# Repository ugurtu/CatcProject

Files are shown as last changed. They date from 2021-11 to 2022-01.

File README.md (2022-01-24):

### CatcProject

This repository provides for the sensor Cube and its programms the following directories:
- building up the DHT-22 Sensor
- a code for a simple modell to use the DHT22 and the LEDs in combination. 
- The directory sensor Cube contains the whole code of the 4 x 4 x 4 LED Cube. 
- There is also the possibility to read out the Serial Port with the help of the python programs which are included in this repository. 

### General Information

- For the Arduino is the Arduino provided IDE used. 
- We used an Arduino UNO and Arduino ATMega 2560.
- For python used is PyCharm by JetBrains.

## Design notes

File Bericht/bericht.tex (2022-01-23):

\documentclass{article}
\usepackage{times}
\usepackage[nohead,bottom=3cm,top=2cm,a4paper]{geometry}
\usepackage[table]{xcolor}
\usepackage{graphicx}
\usepackage[nswissgerman]{babel}
\usepackage{listings}
\usepackage{blindtext}
\usepackage{enumitem}
\usepackage{xurl}
\usepackage{lipsum}
\usepackage{tikz}
\usepackage{hyperref}
\usepackage{float}
\usepackage{fontawesome}
\usepackage{mathtools}
\usetikzlibrary{positioning}
\usepackage{titletoc,tocloft}
\setlength{\cftsubsecindent}{2cm}
\setlength{\cftsubsubsecindent}{4cm}
\dottedcontents{section}[1.5em]{}{1.3em}{.6em}
\usepackage{amssymb,amsmath,amsthm}
\graphicspath{ {./results/} }
\usetikzlibrary{shadows,matrix} % Shadows for nodes
\usetikzlibrary{arrows.meta}
\title{Report aus dem Projekt sensor Cube}
\newlength\mylength
\setlength\mylength{\dimexpr.42\columnwidth-2\tabcolsep-0.42\arrayrulewidth\relax}
\usepackage[section]{placeins}
\def\l@subsection{\@tocline{2}{0pt}{2.5pc}{5pc}{}}	
\definecolor{Gray}{gray}{0.9}
\makeatletter
\renewcommand*\l@section{\@dottedtocline{1}{1.5em}{2.3em}}
\makeatother
\usepackage{varioref}

\author{von Ugur Turhal, Berkan Kurt \& Silvan Lenzlinger}
\begin{document}
\maketitle
\tableofcontents
%\addtocontents{toc}{\protect\thispagestyle{empty}}
\newpage
\begin{center}
\textbf{Abstract}
\end{center}
Dieses Report Dokument ist im Rahmen der Vorlesung, Rechenarchitektur \& vertrauenwürdiges Rechnen entstanden. Das Ziel war ein 4 x 4 x 4  Cube zu löten und diesen mit einem digitalen Luftfeuchtigkeits-\& Temperatursensor auszustatten.
Dieser soll anhand der Luftfeuchtigkeit und Temperatur, spezifische Muster ausgeben, welche uns verraten ob die Werte ideal sind für ein angenehmes Einschlafen. Alle Dokumente und Programme sind auffindbar unter: \begin{center}
\faGithub \text { }  \url{https://github.com/ugurtu/CatcProject}
\end{center}

%%%%
\section{Einleitung}
Als wir im November uns als Team zusammengesetzt haben war die Projektidee sofort klar. Wir wollten mit dem Projekt etwas schaffen, welches uns im alltäglichen Leben auch über den Projektzeitraum hinaus begleiten soll.
Nach reichlicher Überlegung entschieden wir uns für das Oberthema Schlaf. Wir haben den Schlaf gewählt, weil uns aufgefallen ist, dass wir alle drei unsere Einschlafphase als suboptimal beurteilen würden. Als wir uns über die Ursachen und Gründe für unseren suboptimalen Einschlafprozess ausgetausscht haben, kamen wir zum Entschluss, dass wir uns mit der optimalen Raumtemperatur nie auseinandergesetzt haben. Diese ist vor allem im Winter wichtig, da die Raumtemperatur sich zu dieser Jahreszeit oftmals über der optimalen Raumtemperatur, bedingt durch das Überheizen, befindet. Im nachfolgenden Report werden wir darüber reden, wie wir ein Gadget erstellt haben, welches uns hilft, dieses Problem zu lösen.

\section{Aufteilung}
\textbf{Ugur:} Bestellung, funktionsfähiges \glqq Circuit-Modell\grqq auf Tinkercad ohne DHT-22 Sensor, Programmierung des Python Codes zum Auslesen des Serial-Ports, C++ -Code Grundgerüst für den Cube und Jigs vorbereiten. Die Einzelnen Layers Löten. Siehe Kapitel \ref{section:Jigs}. Den Anderen zeigen wie richtig gelötet wird.\\ \\
\textbf{Berkan:} Kupferdraht richten mit Bohrmaschine und zuschneiden damit die Layers gleichmässig aussehen. Schrumpfschläuche über die Kabel ziehen und verlöten, welche mit den Layers Verbunden sind (Kathode), mit Hilfe von Ugur. Case aus Plexiglas herstellen mit Möglichkeit den Arduino in eine sichere Umgebung zu platzieren und einer Türmechanismus ähnlichen Oberfläche. \\ \\ \textbf{Silvan:} 88 LEDs in Form bringen mit Hilfe der Jigs. Mithilfe von Berkan und Ugur alle Layers verlöten Siehe Kapitel \ref{section:result} so dass ein Cube entsteht Siehe Kapitel \ref{section:Jigs}. Code von Ugur verfeinern, Fehler erkennen und ein clean Code entwickeln und Methodennamen anpassen. Cube Nachlöten falls etwas unsauber verlötet wurde. \\ \\
\textbf{Alle:} Bericht schreiben und den sensor Cube testen. 

\section{Jigs/Werkzeuge}
\label{section:Jigs}
Als Jigs werden Hilfsmittel bezeichnet, die beim Prozess des Fertigstellen das Leben vereinfachen. 
\begin{itemize}
\item Ein Raster aus Holz, in welchem die LEDs reingestellt und verlötet wurden. Siehe Abbildung \ref{fig:jig2}.
\item Ein Holzbrett, mit welchem die Anode und Kathode in Form gebracht wurden. Siehe Abbildung \ref{fig:jig1}
\item Eine Bohrmaschine, welche den Kupferdraht gerade gewickelt hat.
\item Ein Schraubstock, welches den Kupferdraht hielt.   
\end{itemize}

\begin{figure}[!h]
\begin{center}
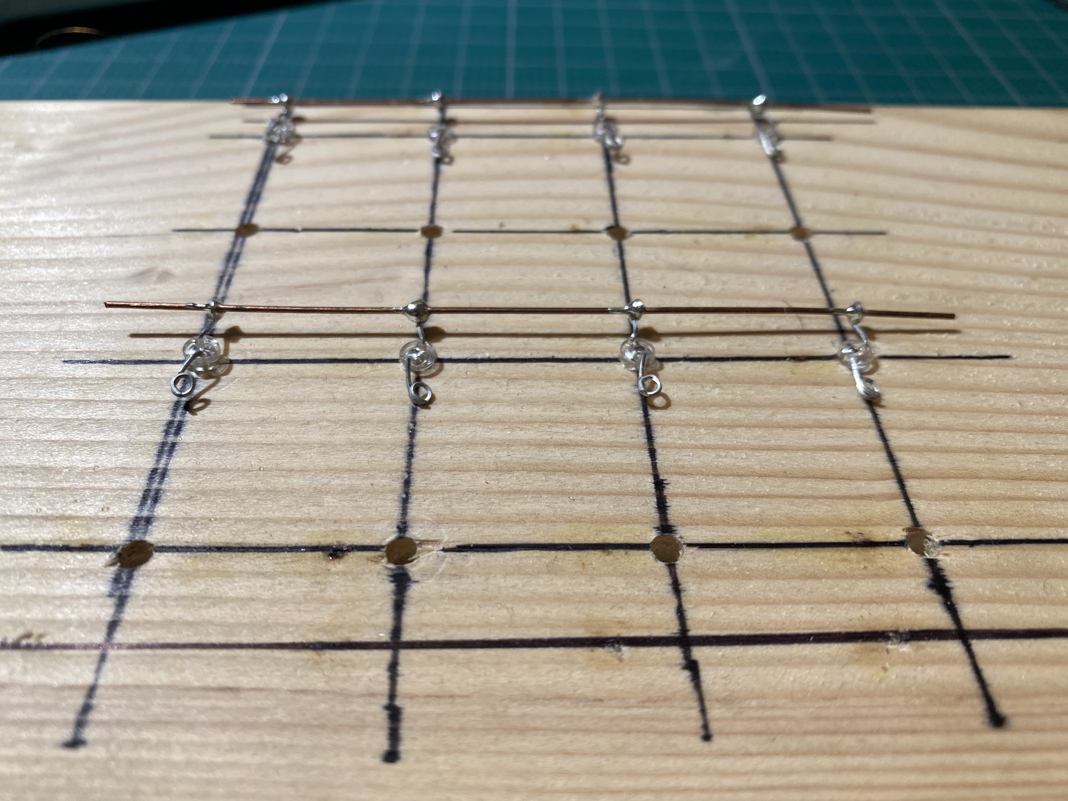
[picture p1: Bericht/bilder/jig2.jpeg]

\caption{Jig für die Layers}
\label{fig:jig2}
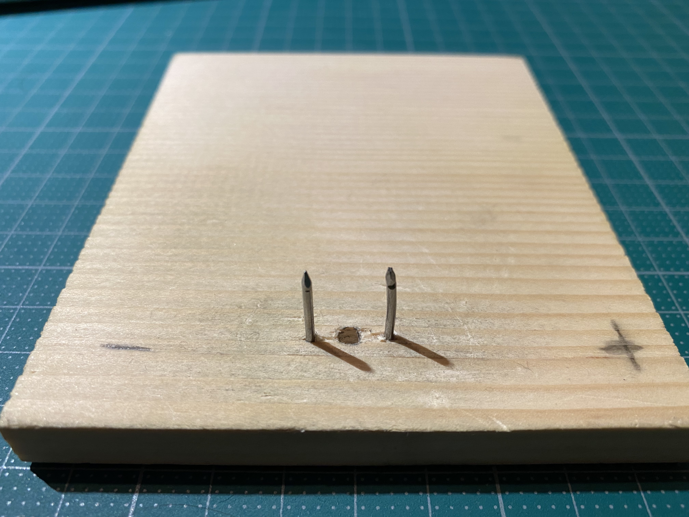
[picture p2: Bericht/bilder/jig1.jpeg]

\caption{Jig für die LEDs}
\label{fig:jig1}
\end{center}
\end{figure}

\noindent Die folgenden Werkzeuge wurden für die Kommunikation und als Austausch verwendet.
\begin{itemize}
\item GitHub, sorgte für einen reibungslosen Austausch.
\item WhatsApp, auf welchem die Meetings festgelegt wurden.
\item Zoom, für Onlinemeetings, falls jemand nicht anwesend war.
\item \LaTeX \text{ }für die Dokumentenerfassung.
\end{itemize} 
\section{Sammeln der Daten}
Bevor das Projekt begann, wurde für die Sicherstellung des Projektes der Sensor anhand des Serialports ausgelesen. Mittels Python Programmen wurde die Raumtemperatur gesammelt und geplotet. Genauere Aufbauinformationen findet man im Dokument:\textbf{ Aufbau.pdf}. Das Dokument befindet sich auf dem angegebenen GitHub Repository: \begin{itemize}
\item \url{https://github.com/ugurtu/CatcProject/blob/main/Aufbau\%20DHT\%2C\%20Programme\%20und\%20Daten/Aufbau.pdf}
\end{itemize} Den spezfischen Python Code findet man unter:
\begin{itemize}
\item  \url{https://github.com/ugurtu/CatcProject/tree/main/SerialPort_python}
\end{itemize}
Diesem Dokument aber liegen sowohl der Aufbau des Sensors und auch das Pythonprogramm bei. Wenn man Lüftet, sollte der Sensor in einer bestimmten Zeit eine Reaktion zeigen. Diese Reaktion verhaltet sich in Form von einem entsprechend angehenden LED Lämpchen. Dieses Testen und auslesen des Sensors diente für uns als Sicherstellung. Somit wurde uns klar, dass wir einen funktionstüchtigen Sensor besitzen, welchen wir für dieses Projekt ohne Probleme verwenden konnten.
\begin{figure}[!h]
\begin{center}
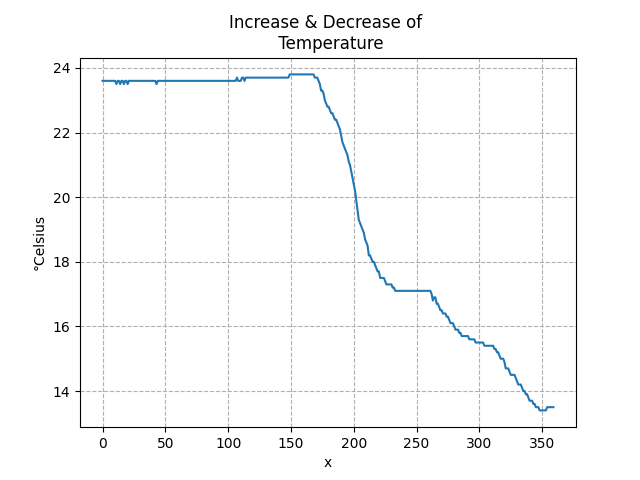
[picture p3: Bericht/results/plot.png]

\caption{Plot des Temperatur Anstiegs und der Abfall}
\label{fig:decrease}
\end{center}
\end{figure}
\begin{figure}[!h]
\begin{center}
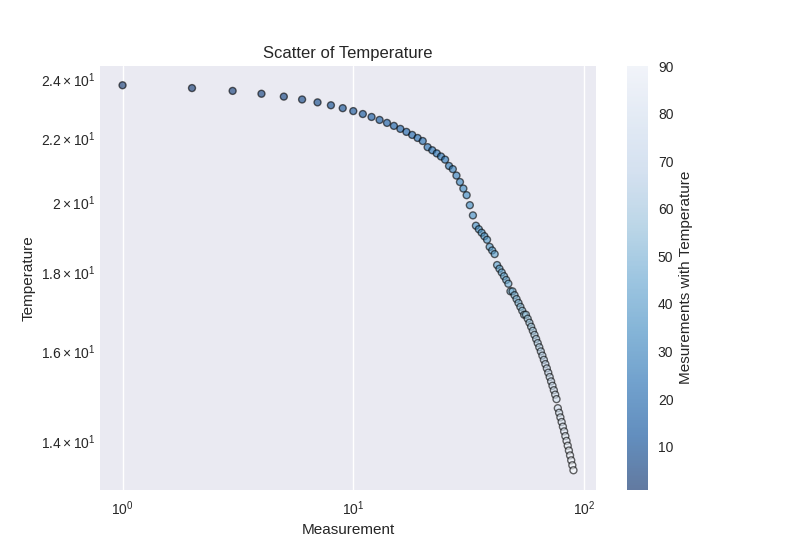
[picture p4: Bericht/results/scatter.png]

\caption{Scatter Plot des Temperatur Abfalls}
\label{fig:scatter}
\end{center}
\end{figure}
\vfill
\begin{figure}[!h]
\begin{center}
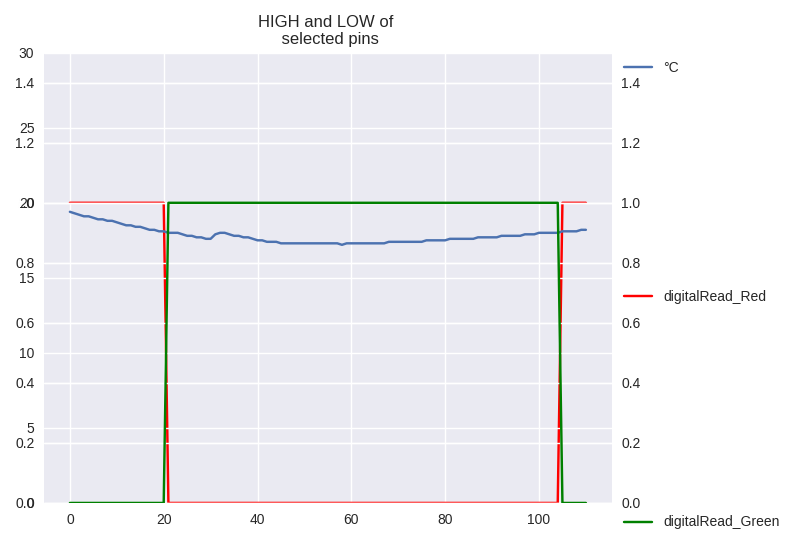
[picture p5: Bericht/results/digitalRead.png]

\caption{HIGH und LOW in einem ersten Test}
\label{fig:highlow}
\end{center}
\end{figure}
\newpage
\subsection{Erkenntnisse durch die Daten}
In der Abbildung \ref{fig:decrease} und \ref{fig:scatter} sieht man wie sich die Temperatur bei offenem Fenster zunehmend verringert. Somit hatten wir Gewissheit, dass der Sensor relativ schnell reagiert und für unser Projekt verwendbar ist. Die x - Achse in der Abbildung \ref{fig:decrease} ist die Zeit. Die Abbildung \ref{fig:scatter} ist Mesurement als 100 Messpunkte definiert. Alle doppelten Daten aus Abbildung \ref{fig:decrease} wurden ignoriert. In der Abbildung \ref{fig:highlow} sollen die zwei Farben, grün und rot, die Farben unserer LED’s und den Zustand HIGH and LOW repräsentieren. Sobald die Temperatur unter 18$^\circ$ C betrug, schalteten sich die grünen LED’s an (HIGH) und die roten LED’s aus (LOW). Damit wurde angezeigt, dass die Bedingung für das Einschlafen optimal ist. Sobald das Fenster wieder geschlossen und die Raumtemperatur damit wieder zugenommen hat, schalteten sich die grünen LED’s aus (LOW) und die roten LED’s gingen wieder an (HIGH).

\section{Umsetzung}
Unser Projekt hat in mehrheitlich sechs Phasen stattgefunden. Diese waren:
\begin{enumerate}[label=(\roman*)]
\item Einkauf
\item Prototyp auf Tinkercad
\item Einzelne Layers verlöten mit LEDs
\item Layers zu einem Cube verlöten
\item Cube mit Arduino verbinden
\item Case
\end{enumerate}
\textbf{Erster Punkt} Wir haben einige Sachen bewusst doppelt gekauft. Falls etwas defekt gewesen wäre, hätten wir keine Zeitengpässe gehabt. \\ \\ 
\textbf{Zweiter Punkt} Dieses folgende umgesetzte \glqq Circuit-Modell\grqq \text{ }wurde von der Grundstruktur so übernommen, allerdings soll angemerkt werden, dass dieses Modell mit einem Arudino UNO erstellt wurde, da kein Arduino ATMega auf Tinkercad zur Verfügung stand. Siehe: Abbildung \ref{fig:tinkercad}
\begin{figure}[h!]
\begin{center}
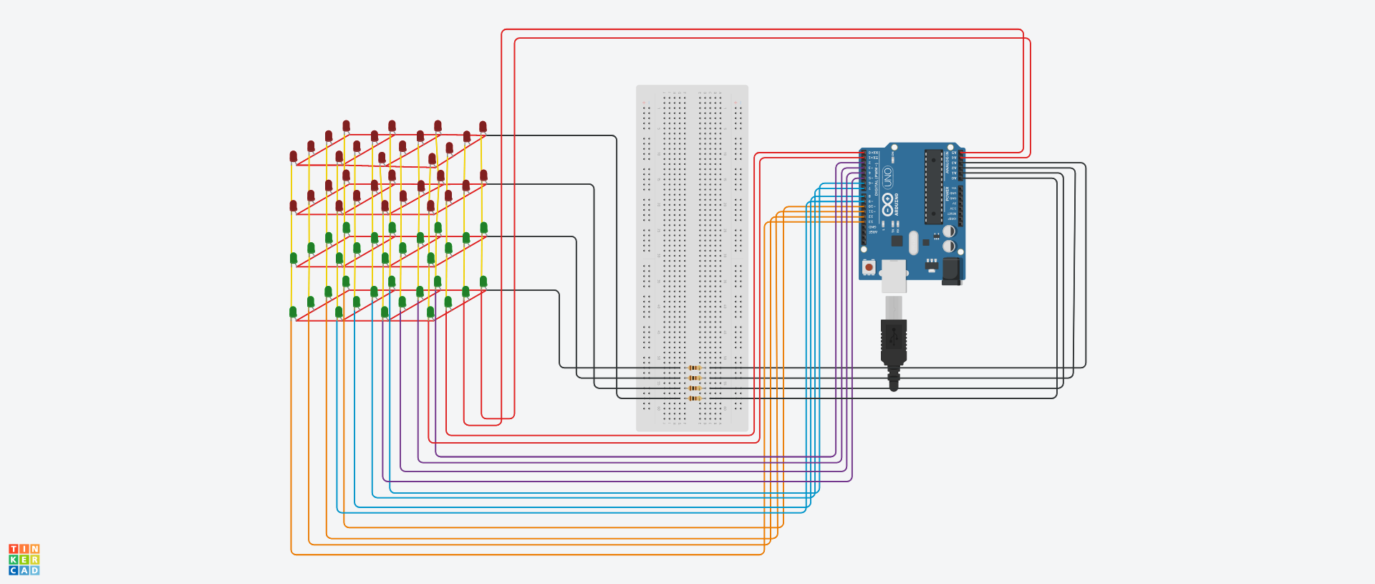
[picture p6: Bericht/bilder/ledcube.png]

\caption{LED Cube Circuit mit einem Arduino UNO}
\label{fig:tinkercad}
\end{center}
\end{figure}
\\ \\
\textbf{Dritter Punkt} Die Layers, welche in der Abbildung 7 zu sehen sind leiten den Strom. Es gibt vier davon. 
\begin{figure}[!h]
\begin{center}
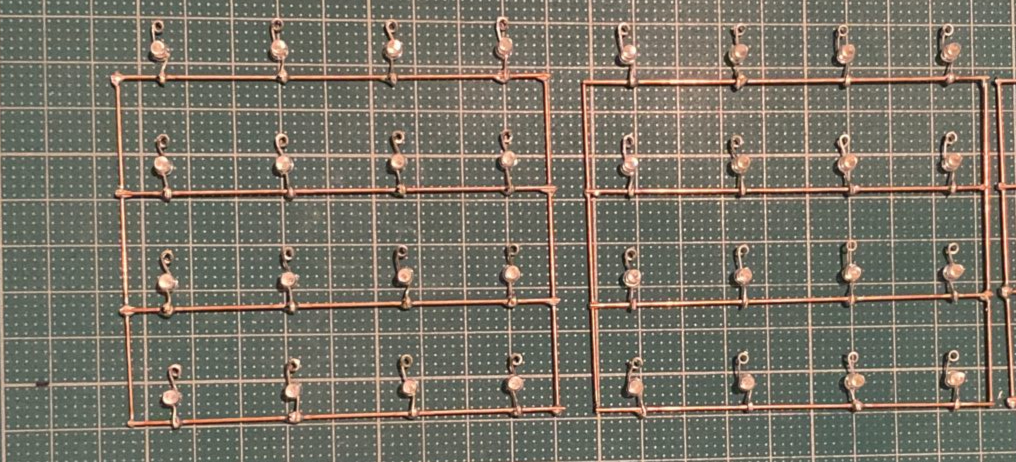
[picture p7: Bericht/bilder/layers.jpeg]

\label{fig:anode}
\caption{Anode mit dem Kupferdraht verlötet, zu sehen zwei Layers}
\end{center}
\end{figure}
\\ \\
\textbf{Vierter Punkt} Die Layers, werden durch vertikale Kupferdrähte miteinander verbunden, dies sorgt dafür dass die Kathode verbunden ist. Danach wurde der Cube mit der Europlatine verlötet. Damit jede Ebene, durch den Mikrocontroller Strom bekommt, wurden zusätzlich vier Kupferdrähte jeweils treppenförmig mit den vier Layers verbunden. Jeder Layer ist jeweils mit einem 100 $\Omega$ Widerstand verlötet. Das Datasheet für die LEDs sieht ein Peak Forward Current von 60 mA vor. Daher wurden 100 $\Omega$ verwendet.\footnote{\url{https://www.reichelt.com/de/en/led-3-mm-leaded-green-125-mcd-25--evl-1224-10sygc-p230786.html}} \begin{align}
U = R \cdot I \\
U \coloneqq 5 V, I \coloneqq 0.060 A \\
\frac{5V}{0.060A} = 83.333 \Omega \\
\approx 100 \Omega
\end{align}
Danach wurde auf der linken Seite des sensor Cubes der DHT-22 verlötet. Als letzter Schritt wurden die Kuperdrähte der Kathode und die Pins des Sensors mit Kabeln verlötet, isoliert und mit den Stiftleisten verlötet. Siehe Abbildung \ref{fig:kathode}. 
\begin{figure}[!h]
\begin{center}
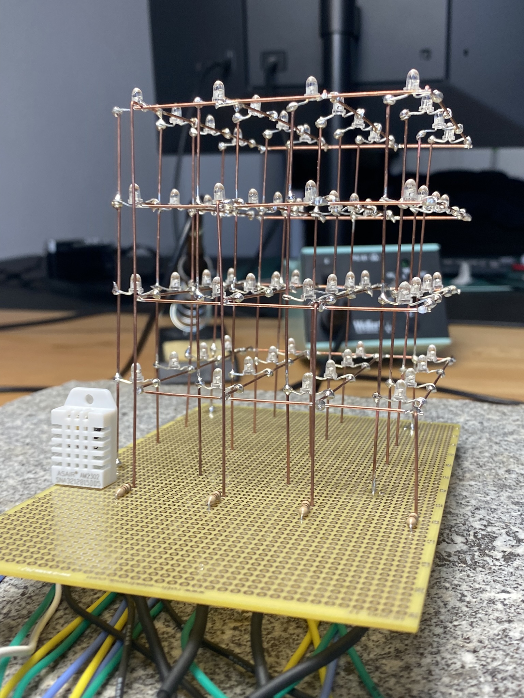
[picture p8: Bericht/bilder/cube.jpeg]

\caption{sensor Cube gelötet}
\label{fig:kathode}
\end{center}
\end{figure}\newpage
\noindent \textbf{Fünfter Punkt}
Der 5 Schritt war die entscheidende Phase, da alles fertig war wurden die Pins verbunden. hier eine Übersicht:
\begin{enumerate}
\item A0 $\rightarrow$ versorgt Layer 0 mit Strom.
\item A1 $\rightarrow$ versorgt Layer 1 mit Strom.
\item A2 $\rightarrow$ versorgt Layer 2 mit Strom.
\item A3 $\rightarrow$ versorgt Layer 3 mit Strom.
\end{enumerate}
\textbf{DHT-22 Pins}
\begin{enumerate}
\item DHT-22 Anode $\rightarrow$ 5V.
\item DHT-22 Kathode $\rightarrow$ GND.
\item DHT-22 Digital-Pin $\rightarrow$ 50.
\end{enumerate}
Die Kathode der LEDs sind wie in Abbildung \ref{fig:kathodepins} aufgeteilt. Die Pins werden durch jeweils zwei For-Loops als OUTPUT initialisiert. Einmal für die Layers und einmal für die \glqq Spalten\grqq. Dies hat den Vorteil, dass wir nun durch dieses System jede LED einzeln ansteuern.
\tikzset{darkstyle/.style={circle,draw,fill=gray!40}}
\begin{figure}[hbt!]
\centering
\begin{tikzpicture}
\begin{scope}[every node/.style={circle,thick,draw,fill=gray!40,level distance=200mm,}]
    \node (D48) at (0,0) {D48};
    \node (D46) at (2,0) {D46};
    \node (D44) at (4,0) {D44};
    \node (D42) at (6,0) {D42};
    
    \node (D46) at (2,0) {D46};
    \node (D44) at (4,0) {D44};
    \node (D42) at (6,0) {D42};
    
    \node (D40) at (0,-2) {D40};
    \node (D38) at (2,-2)  {D38};
    \node (D36) at (4,-2) {D36};
    \node (D34) at (6,-2) {D34};
    
    \node (D32) at (0,-4) {D32};
    \node (D30) at (2,-4)  {D30};
    \node (D28) at (4,-4) {D28};
    \node (D26) at (6,-4) {D26};
    
    \node (D24) at (0,-6) {D24};
    \node (D22) at (2,-6)  {D22};
    \node (A5) at (4,-6) {A5};
    \node (A4) at (6,-6) {A4};
    
\end{scope}

\begin{scope}[>={Stealth[black]},
              every node/.style={fill=gray!40,circle,thick},
              every edge/.style={draw=red,very thick}]
     \draw [color=red!100,->,line width=1] (A4) -- (A5);
     \draw [color=red!100,->,line width=1] (A5) -- (D22);
     \draw [color=red!100,->,line width=1] (D22) -- (D24);
     \draw [color=red!100,->,line width=1] (D24) -- (D32);
     \draw [color=red!100,->,line width=1] (D32) -- (D40);
     \draw [color=red!100,->,line width=1] (D40) -- (D48);
     
     \draw [color=red!100,->,line width=1] (D48) -- (D46);
     
     \draw [color=red!100,->,line width=1] (D46) -- (D38);
     \draw [color=red!100,->,line width=1] (D38) -- (D30);
     \draw [color=red!100,->,line width=1] (D30) -- (D22);
     
     \draw [color=red!100,->,line width=1] (D46) -- (D44);
     \draw [color=red!100,<-,line width=1] (D44) -- (D36);
     \draw [color=red!100,<-,line width=1] (D36) -- (D28);
     \draw [color=red!100,<-,line width=1] (D28) -- (A5);
     
     \draw [color=red!100,->,line width=1] (D44) -- (D42);
     \draw [color=red!100,->,line width=1] (D42) -- (D34);
     \draw [color=red!100,->,line width=1] (D34) -- (D26);
     \draw [color=red!100,->,line width=1] (D26) -- (A4);
   
\end{scope}
\end{tikzpicture}
\caption{Obere Ansicht des sensor Cubes mit den Verbundenen Pins und des Stromflusses}
\label{fig:kathodepins}
\end{figure} \\ \\
\textbf{Sechster Punkt} Als der sensor Cube fertig war und wir somit wussten, dass wir das Ziel erreicht haben, haben wir uns auf die Suche nach einem passenden Case gemacht. In einem Meeting wurde die Entscheidung getroffen, ein Case aus Plexiglas herzustellen. In verschiedenen Geschäften suchte man das passende Plexiglas, nach Scharnieren und Klebstoffen. Das Plexiglas wurde mit den passenden Massen geschnitten und schlussendlich zu einem Rechteck zusammengeklebt. Anschliessend wurden in die Seite des Case, sowie in die Europlatine zwei Schaniere montiert. Dies sollte uns ermöglichen, einen Türähnlichen Mechanismus zu haben. sind die Kabel und das Arduino in Sicherheit. Ausserdem wurde ein Loch in die Seite des Case gefräst, um die Stromversorgung zu gewährleisten Ebenfalls können Reparaturen vorgenommen werden, falls ein Kabel defekt ist. Für das Ergebnis siehe Abbildung \ref{fig:cubewcase}.
\begin{figure}[!h]
\begin{center}
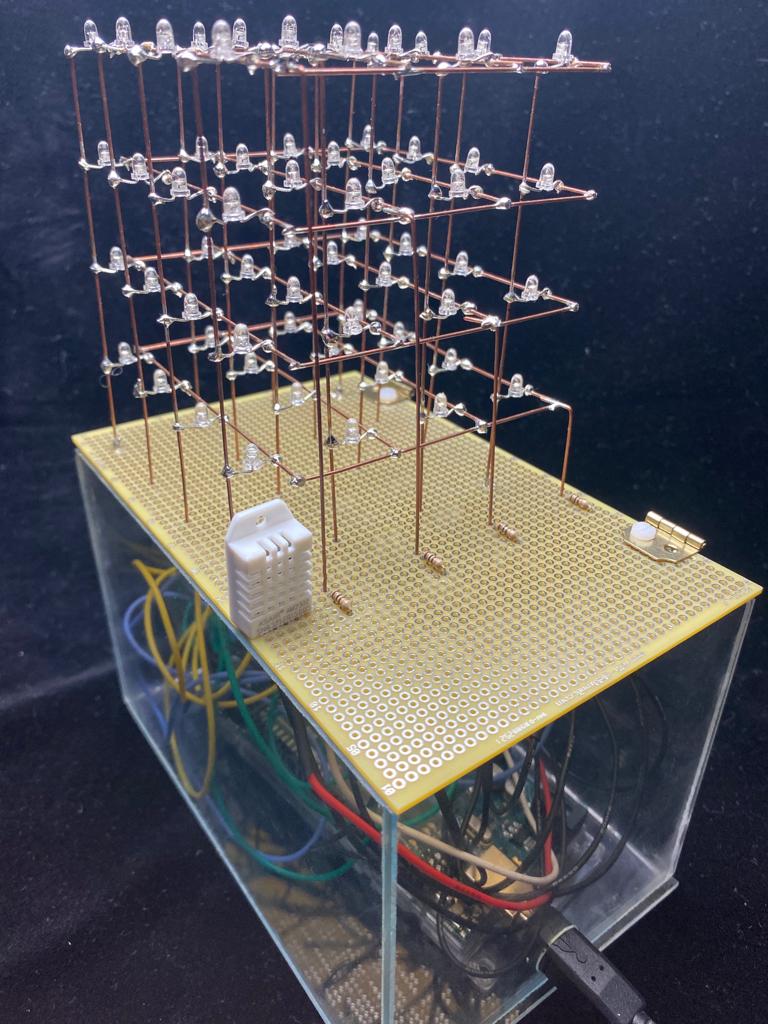
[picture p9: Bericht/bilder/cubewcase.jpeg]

\caption{Cube mit Case}
\label{fig:cubewcase}
\end{center}
\end{figure}
\newpage
\section{Resultat}
\label{section:result}
Der Cube ist unserer Meinung nach genau und symmetrisch gelötet. Auch wenn es noch Raum nach oben gibt, sind wir mit dem Endprodukt sehr zufrieden. Zudem lässt das durchsichtige Case einen direkten Blick auf das Innenleben des Cubes zu. Da für die Verdrahtung sehr wenig Platz war, haben wir Schrumpfschläuche an den Enden
der Kabel benutzt. Diese verhindern einen allfälligen Kurzschluss. Danach hatten wir zwischen dem Arduino und allen LEDs sowie dem Sensor eine sichere Verbindung. In Abhängigkeit von den Messdaten kann der Cube die folgenden fünf Muster wiedergeben:

\begin{itemize}
\item Temperatur: $<$ 15$^\circ$ C Raumtemperatur
\begin{itemize}
\item[$\square$] Dynamisches/pulsierendes Feedback
\end{itemize}
\item Temperatur: $\geq$ 15$^\circ$ C Raumtemperatur $\leq$ 18$^\circ$ C
\begin{itemize}
\item[$\square$] Feuchtigkeit: $<$ 30 \% Luftfeuchtigkeit im Raum
\begin{itemize}[label=$\ast$]
\item Dynamisches Regenmuster von unten nach oben 
\end{itemize}
\end{itemize}
\begin{itemize}
\item[$\square$] Feuchtigkeit: $\geq$ 30 Luftfeuchtigkeit im Raum $ \leq$ 60  \%
\begin{itemize}[label=$\ast$]
\item Die zwei grünen Levels leuchten statisch
\end{itemize}
\end{itemize}
\begin{itemize}
\item[$\square$] Feuchtigkeit: $>$ 60 \% Luftfeuchtigkeit im Raum
\begin{itemize}[label=$\ast$]
\item Dynamisches Regenmuster von oben nach unten
\end{itemize}
\end{itemize}
\item Temperatur: $> $ 18$^\circ$ C Raumtemperatur
\begin{itemize}
\item[$\square$] Dynamisches/ propellerartiges Leuchtmuster
\end{itemize}
\end{itemize}
Durch die visuelle Wiedergabe der LEDs hat man Zeitnah ein Feedback über das Raumklima. Die dynamischen Leuchtmuster lassen sich schnell interpretieren und es kann entsprechend reagiert werden. Nach Anpassungen des Raumklimas leuchtet das statische Muster in grün. Danach steht einer guten Einschlafphase \glqq nichts\grqq \text{ }mehr im Weg.

\section{Gewonnene Erkentnisse}
Dieser Abschnitt besteht nicht nur aus einer Erkenntnis sondern aus mehreren Erkenntnissen. Deshalb sollen in den nachfolgenden Abschnitten folgende Erkentnisse angesprochen werden: 
\begin{enumerate}
\item Die Fähigkeit beziehungsweise die Nützlichkeit des sensor Cubes im Alltag,
\item Erkenntnisse über das verwendete Material,
\item Zeitmanagement bis zur Abgabe,
\item Verbesserungen für ein nächstes Projekt.
\end{enumerate}

\subsection{Nützlichkeit im Alltag}
Das unser Cube im Stande ist auf unterschiedlichliche Temperaturen und eine veränderte Luftfeuchtigkeit zu reagieren ist ausser Frage. Dies wurde in einem Praxistest bei allen drei Gruppenmitgliedern zu Hause getestet. Das bei einer spezifischen Luftfeuchtigkeit \& Temperatur spezifische festgelegte Muster als Feedback angezeigt werden sollen ist vorhanden. \newline Wir sind per E-Mail mit Schlafprofessor Prof. Dr. Björn Rasch in Kontakt getreten, um zusätzliche Informationen über die optimale Schlaftemperatur und Luftfeuchtigkeit zu erhalten. Aus einer E-Mail von 03.01.22 wurden drei Punkte deutlich. 
\begin{enumerate}
\item Der Schlaf steht in Korrelation mit der psychologischen Verfassung des Benutzers des Kubus.
\item Die Temperatur für den optimalen Schlaf hängt von dem Microklima unter der Bettdecke ab.
\item Verschiedene Studien kommen zum Schluss, dass 30-50\% oder 30-60\% Luftfeuchtigkeit optimal sind.    
\end{enumerate}
\textbf{Zu Punkt eins} soll keine Stellung genommen werden, da wir über keine fundierte psychologische Ausbildung verfügen, selbst wenn das der Fall wäre, würde dies den Rahmen des Reports sprengen. \\ \\ \textbf{Zu Punkt zwei} sind wir der gleichen Meinung, dass wenn eine Bettdecke zu warm gibt, dies sich auf das Einschlafen negativ auswirkt. Trotzdem hat der Cube das Einschlafen bei allen Gruppenmitgliedern positiv beeinflusst. Somit sehen wir einen direkten Zusammenhang zwischen dem Raumklima und der Qualität des Einschlafens. Wir vermuten, dass durch die zusätzliche Wahl einer passenden Bettdecke die Qualität des Einschlafens weiter verbessert wird. \\ \\ \textbf{Zu Punkt drei}, dass die Luftfeuchtigkeit stimmen muss für den Schlaf/Einschlaf, vorallem in einer kalten Jahreszeit, da kalte Luft relativ trocken ist, kann unser Kubus auch evaluieren. \\ \\
\textbf{Fazit} Die Benutzung des sensor Cubes kann hilfreich sein beim Einschlafen. Allen drei Gruppenmitgliedern hat der sensor Cube geholfen. 
 
\subsection{Das verwendete Material} 
Folgende Komponenten wurden verwendet: 
\begin{enumerate}
\item Kupferdraht
\item Kabel mit einer Litze
\item Arduino UNO 328P $\rightarrow$ Arduino ATMega 2560
\item Lötzinn
\item Flussmittel
\item Schrumpfschlauch
\item Euro-Platine aus Epoxidharz
\item Plexiglas
\item Löt-Station
\item DHT-22
\item LEDs
\item Scharniere
\item Sekundenkleber
\item USB-Stecker - Typ B
\item Multimeter
\item Heissluftföhn
\item Bohrmaschine
\end{enumerate}
In der Tabelle \ref{table:problems} auf der nächsten Seite sollen nur die Teile aufgelistet werden, welche Probleme bereitet haben. Die Komponenten die nicht in der Tabelle sind, haben \textbf{keine} Probleme verursacht.
\begin{table}
    %% \centering % not needed
    \caption{Probleme und Lösungen}
    \rowcolors{1}{}{Gray}
    \begin{tabular}{p{\mylength}|p{\mylength}|p{\mylength}}
        \hline
        \textbf{Komponente} & \textbf{Problem}  &\textbf{Lösung}  \\
        \hline \hline
        Kupferdraht & Der Kupferdraht, welcher bestellt wurde, war beschichtet und ohne Lötzinn war dieser nicht Leitfähig. Die Schicht musste geschmolzen werden oder abgeschliffen werden  & Neuer Kupferdraht wurde erworben\\
        Arduino     & Da wir alle LEDs einzeln ansteuern wollten aber auch den Sensor verbauen mussten, waren wir gezwungen mit i$^2$c zu arbeiten oder mehr Pins haben& Ugur entschied sich im Sinne der Gruppe auf einen Arduino ATMega 2560 umzustellen        \\
        Lötzinn        & Der Lötzinn welcher mitgegeben wurde, war relativ alt und ergab beim ersten Löten Zinnkugeln, welche optisch nicht ansprechend waren & Flussmitttel wurde erworben \\
        Schrumpfschlauch         & Der Schrumpfschlauch der erworben wurde, hatte einen zu kleinen Durchmesser für die Verbingdungskabel &  Schrumpfschlauch mit 3mm, welcher auf eine grösse von 1mm schrumpfte wurde erworben\\
        Euro-Platine aus Epoxidharz   & Bis heute sind wir in der Gruppe nicht einig, ob wir die Euro-Platine anders herum hätten verwenden sollen, da der Lötzinn nicht haftete & -      \\
        Plexiglas   & Wir wollten nicht nur ein Platz für unseren Arduino, sondern auch ein Case für den Cube aus Plexiglas, leider reflektierte das Material die Lichter der LEDs zu stark. Somit war nicht eindeutig erkennbar, welche LED rot oder Grün leuchtete. & Verzicht den Cube in ein Plexiglas gehäuse zu stellen.      \\
        Löt-Station & Die Spitze des Lötkolbens, welcher zur Verfügung gestellt wurde, war oxidiert. Somit war es nicht möglich mit dieser Löt-Station zu löten, entweder musste die Lötspitze gereinigt werden oder eine andere Lötstation musste her. & Ugurs Arbeitgeber verlieh eine professionelle Löt-Station aus.\\
        DHT-22   & Ein Sensor der mitgeliefirt wurde, war defekt. Da wir aber aus Sicherheitsgründen zwei bestellt haben, hatten wir ein Backup & Der zusätzliche Sensor wurde verwendet.      \\
        Sekundenkleber & Die Kombination aus Sekundenkleber und Plexiglas verträgt sich nicht gut. Beim ausprobieren hat Berkan festgestellt das Spuren des Klebers sichtbar werden & Berkan hat trotz der Einschränkung, versucht so sauber wie möglich zu arbeiten\\
        USB-Stecker - Typ B & Der USB-Stecker Typ B war relativ dick. Da wir keine Werkstatt haben, standen uns nur wenige Aufsätze zur Verfügung. Das Loch, welcher für das Kabel gedacht ist, ist ein bisschen Eng. & -  \\
        
        \hline
    \end{tabular}
    \label{table:problems}
\end{table}
\newpage
\subsection{Zeitmangement}
Da wir einen strikten Gantt-Chart befolgt haben, wurde alles nach Zeitplan erledigt. Wir waren mit dem sensor Cube am 31. Dezember 2021 fertig. Somit konnten wir viel testen und uns zusätzliche Gedanken darüber machen, wie wir die Luftfeuchtigkeit zusätzlich in unser Projekt integrieren können. Ausserdem hatten wir genug Zeit um Ästhetische Aspekte, wie die LED Feedbacks und das Case fertigzustellen. Wir können behaupten, dass wir die Verwendung des Gantt-Charts nochmal in einem ähnlichen Projekt einbinden würden, da dieses den Zeitplan relativ gut eingeteilt hat und wir somit immer wieder überprüfen konnten, wo wir stehen.  
\subsection{Verbesserungswürdig}
Wir kamen zum Entschluss, dass wir in einem nächsten Projekt mehr Zeit für die Planung investieren würden. Diese zusätzliche Zeit hätte uns viel Mühe und Zeit erspart. Viele Erkentnisse kamen zu spät, beispielsweise haben wir das Kupfergestell gelötet ohne zu überlegen, wie wir es in die Euro-Platine reinbekommen sollen. Dieses Problem wäre einfacher zu lösen gewesen, wenn wir das Grundgerüst direkt in die Europlatine integriert hätten. Das gleiche Problem hatten wir auch mit unserem Case, welches sich schwerer als gedacht erwies, da wir schon ein fertigen Kubus hatten welchen wir nun mit einem Case austatten wollten. Zudem ist es auch wichtig sich vorher schon Gedanken zu machen ob uns genug Pins zur Verfügung stehen, dass hat uns zwei Tage gekostet, da die Lieferung bisschen verzögert war.
\newpage
\section{Danksagung}
Folgenden Personen/ dem Arbeitgeber soll gedankt werden: \\
\newline \textbf{Frau Sarah-Lia Andrea Wotke}, Sie hat Ugur eine Einführung in das Löten gegeben, er konnte sein Wissen mit Berkan und Silvan teilen. Zu dem hat Sie wichtige Tipps gegeben, wie wir die Kabel isolieren sollten. \newline \newline
\textbf{Herr Prof. Dr. Björn Rasch} an der Universität Fribourg, er hat dem Projekt eine andere Sichtweise gegeben.\newline \newline
\textbf{Herr Ilir Ferati} Welcher wichtige Tipps bezüglich des Gehäusebaus gegeben hat.\newline \newline
Als letztes wollen wir uns bei der \textbf{Abteilung Technik des Telebasels} bedanken. Diese hat uns das nötige Werkzeug zur Verfügung gestellt, welche den Zeitplan sichergestellt haben.

\end{document}

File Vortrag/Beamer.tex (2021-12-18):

\documentclass[aspectratio=169]{beamer}

\usepackage[ngerman]{babel}
\usepackage[utf8]{inputenc}
\usepackage[T1]{fontenc}
\usepackage{tcolorbox}
\usepackage{algpseudocode}
\usepackage{algorithm}
\usepackage{amsmath}
\usepackage{amsfonts}
\usepackage{amssymb}
\usepackage{amsthm}
\usepackage{graphicx}
\usepackage{multicol}
\usepackage{caption}
\PassOptionsToPackage{hyphens}{url}\usepackage{hyperref}
\usepackage{enumerate}
\usepackage{xcolor}
\usepackage{chronology}
\usepackage{tcolorbox}
\usepackage{listings}

\definecolor{mygreen}{HTML}{A5D7D2}   % UBC Blue (primary)

\usecolortheme[named=mygreen]{structure}
\setbeamercolor{section in sidebar shaded}{fg=black}
\usetheme{Hannover}
\title{sleepCube}
\author{Ugur Turhal, Silvan Lenzlinger \& Berkan Kurt}
\institute{Universit\"at Basel}
\date{\today}

\begin{document}

\frame{\maketitle}
%\frame{\tableofcontents}

\section{Projekt Idee}
\begin{frame}[fragile]
\textbf{Projekt Idee}
\begin{enumerate}[(1)]
\item Etwas was im alltag gebraucht werden kann
\item LED Cube
\item Schlaf-Raumtemperatur
\item CS Studenten \& Schlafmangel
\end{enumerate}
\begin{figure}[!h]
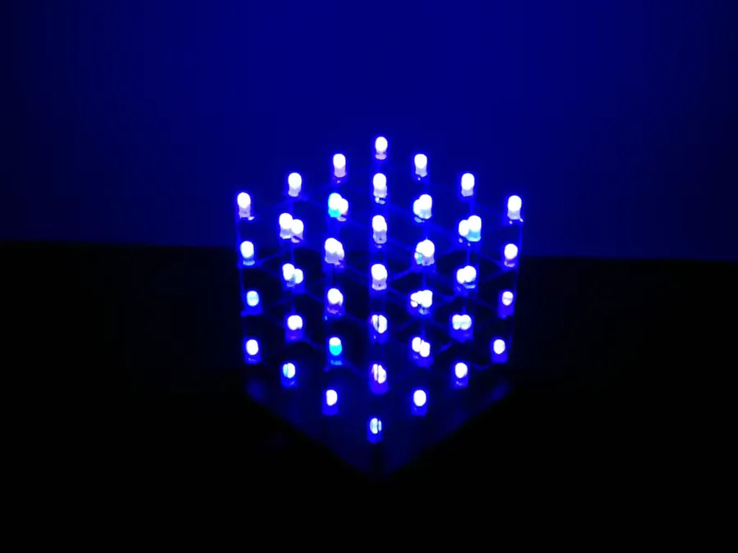
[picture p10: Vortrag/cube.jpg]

\captionof{figure}{4 $x$ 4 $x$ 4 - LED Cube\footnote{\url{https://www.hackster.io/ProMaker_101/4x4x4-led-cube-making-d71684}}} \label{cube} 
\end{figure}
\end{frame}

\section{sleepCube - INFOS} 
\begin{frame}[fragile]
\textbf{sleepCube - INFOS}
\begin{columns}
\begin{column}{0.5\textwidth}
\begin{itemize}
\item Mikrocontroller: Arduino UNO ATMega328
\item Cube Grösse:  4 $\times$ 4 $\times$ 4
\item LED Farben: \textcolor{red}{Rot} \& \textcolor{green}{Grün}, \underline{keine} RGB LEDs

\end{itemize}

\end{column}

\begin{column}{0.5\textwidth}
\begin{itemize}
\item DHT22 für Temperaturmessgerät
\item Genauer als TMP36
\item \textcolor{red}{Rot-Leuchten} $<$15$^{\circ}$ C oder $>$18$^{\circ}$ C
\item \textcolor{green}{Grün-Leuchten} $\geq$15$^{\circ}$ C oder $\leq$18$^{\circ}$ C
\end{itemize}
\end{column}

\end{columns}
\end{frame}

\section{Mögliche Schwierigkeiten} 
\begin{frame}[fragile]
\textbf{Mögliche Schwierigkeiten}
\begin{itemize}
\item Sauberes Löten
\item Symmetrischer Cube z.B. Abstände
\item Ästhetik
\item Gestell (Gehäuse z.B. aus Plexiglas)
\item Digitaler Temperatur Sensor (Noch nie benutzt)
\end{itemize}
\begin{columns}
\begin{column}{0.45\textwidth}

\end{column}
\begin{column}{0.5\textwidth}

\end{column}

\end{columns}
\end{frame}

\section{Timeline} 
\begin{frame}[fragile]
\textbf{Timeline}
\begin{figure}

\begin{tikzpicture}[scale=0.5,every node/.style={outer sep=5pt}]
    %Notation: {year, the title of the event}
    %NOTE! Everyting is zero-based
    \def\ourInfo{{
        {"5. Dezember","Ugur: DHT und LEDs Testen auf Breadboard"},
        {"10. Dezember","Silvan \& Berkan überlegen Aufbau"},
        {"20. Dezember","Aufbau umsetzen: Löten etc."},
        {"24. Januar 2022","Abgabe"},
    }}
    \pgfmathsetmacro{\length}{3}% Zero based.

    % Loop through the array containing all events.
    \foreach \i in {0, ..., \length}{
        \pgfmathsetmacro{\year}{\ourInfo[\i][0]}% Get the left cell (year)
        \pgfmathsetmacro{\eventName}{\ourInfo[\i][1]}% Get the right cell (event name)
        \draw[thick,mygreen] (0,-2*\i-2)--(0,-2*\i);% Draw vertical line
        \ifnum \i=1 % Should be in red text
          \draw(0,-2*\i-1) node[black, right, align = left]{\eventName};% Display the event name
          \draw(0,-2*\i-1) node[black, left] {\year};
        \else % Should be in black text
           \draw(0,-2*\i-1) node[right, black]{\eventName};% Display the event name
           \draw(0,-2*\i-1) node[left] {\year};% Display the year
        \fi
    }
    % Draw the bullet with the dash
    \foreach \i in {0, ..., \length}{
        \filldraw[draw = white, fill = mygreen,thick] (0,-2*\i-1) circle (5pt);
        \draw[thick,mygreen] (-12pt,-2*\i-1)--(0,-2*\i-1);
    }
\end{tikzpicture}
\end{figure}
\end{frame}

\section{Fragen} 
\begin{frame}[fragile]
\textbf{Fragen}

\begin{center}
Fragen?
\end{center}

\end{frame}

\end{document}

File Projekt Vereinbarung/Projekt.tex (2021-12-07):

\documentclass{paper}
\usepackage[nswissgerman]{babel}
\usepackage{color}
\usepackage{enumerate}
\usepackage{amsmath}
\usepackage{fancyhdr}
\usepackage{pdfpages}
\usepackage{hyperref}
    \usepackage[a4paper, total={6.5in, 8in}]{geometry}
\usepackage{collcell,booktabs,siunitx}
\usepackage{xparse}
\usepackage{pgfgantt}
\newcolumntype{F}{>{\collectcell\rememberF}c<{\endcollectcell}}
\newcolumntype{M}{>{\collectcell\rememberM}c<{\endcollectcell}}
\newcolumntype{P}{>{\collectcell\computeP}r<{\endcollectcell}}

\newcommand{\rememberF}[1]{%
  \gdef\kompo{#1}#1%
}
\newcommand{\rememberM}[1]{%
  \gdef\preis{#1}#1%
}

\ExplSyntaxOn
\NewDocumentCommand{\computeP}{}
 {
  \bfseries\fp_eval:n { round ((\kompo*\preis) , 3 ) }
 }
\ExplSyntaxOff

\definecolor{green}{rgb}{0,0.6,0}
\definecolor{myblue}{RGB}{205,214,230} %BLUE
\definecolor{mygreen}{RGB}{165, 215, 210}     
\begin{document}
\pagestyle{fancy}
\fancyhead[L]{Projekt sleepCube\\ CatcHS21}                  
\fancyhead[C]{}                       
\fancyhead[R]{Silvan Lenzlinger\\Berkan Kurt\\Ugur Turhal}
\begin{abstract}
\noindent Das Projekt, sleepCube, ist ein 4 x 4 x 4 Arduino LED-cube. Dieser LED-cube ist mit einem DHT22 Sensor ausgestattet. Dieser Sensor kann die Luftfeuchtigkeit und die Temperatur messen. Für das Projekt ist die letztere Funktion von relevanz.
\end{abstract}

\section*{Ziel des Projektes} Das Endprodukt, soll als Nachttischlampe dienen, welche anzeigt ob eine angehneme Raumtemperatur für das Schlafen vorhanden ist oder nicht. Diese "angehneme Raumtemperatur für das Schlafen" wird mit zwei Farben angezeigt:\begin{enumerate}[(a)]
\item \textcolor{red}{ROT} für eine nicht angehme Schlafenstemperatur:\\ $<$(15 - 18)$^{\circ}$C oder $>$ (15 - 18)$^{\circ}$C  
\item \textcolor{green}{GRÜN} für eine angehme Schlafenstemperatur:\\ (15 - 18)$^{\circ}$C 
\end{enumerate}
\section*{Mitglieder}
Im Projekt involviert sind folgende Personen: 
\begin{enumerate}[(1)]
\item Silvan Lenzlinger
\item Berkan Kurt 
\item Ugur Turhal
\end{enumerate}
\section*{Komponenten und Kosten}
Für das Projekt benötigte Komponenten, sowohl die Kosten der Komponenten:

\begin{center}
\begin{tabular}{c F M P}
\toprule
  \multicolumn{1}{c}{Komponenten} &
  \multicolumn{1}{c}{Anzahl} &
  \multicolumn{1}{c}{\textbf{CHF}} \\
\midrule
Arduino Uno ATMega 328 & 1 & 24.94 &  \\
EVL 1224-10SURC LED, 3 mm, bedrahtet, rot, 400 mcd, 20$^{\circ}$ & 40 & 0.20 &  \\
EVL 1224-10SYGC LED, 3 mm, bedrahtet, grün, 125 mcd, 25$^{\circ}$ & 40 & 0.20 &  \\
Widerstand 220$\Omega$& 8 & 0.15 & \\
28 AWG Elektrischer Draht 13m&1 & 18.50 & \\
DELOCK Schrumpfschlauch 86264&1 & 6.40 & \\
Stannol HS10 2510 Lötzinn, bleifrei Spule Sn99,3Cu0,7 250 g 1 mm &1 & 18.15 & \\
SL 1X40W 2,54 40pol. Stiftleiste, gewinkelt, RM 2,54 & 5 & 0.40 & \\
RE 200LF Europlatine, Epoxyd, verzinnt 160x100 mm&1 & 6.90 & \\
DEBO DHT 22 Entwicklerboards - Temperatur- \& Feuchtigkeitssensor, DHT22 &2 & 6.00 & \\
STECKBOARD 1K2V Experimentier-Steckboard 640/200 Kontakte & 1 & 6.50 &\\
MagiDeal USB A Male to Female Extenstion Kabel mit Switch On/Off  & 1 & 3.96 &\\ \bottomrule
\textbf{TOTAL} &  0 & 0 & 116.55 \\
\bottomrule
\end{tabular}
\end{center}
\subsection*{Links zu den Websiten}
\begin{enumerate}[(a)]
\item \url{https://www.reichelt.de/de/de/widerstand-kohleschicht-220-ohm-0207-250-mw-5--1-4w-220-p1382.html?r=1}
\item \url{https://www.amazon.de/MagiDeal-Female-Extenstion-Kabel-Switch/dp/B01IP1HDUU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}
\item \url{https://www.reichelt.com/ch/de/index.html?ACTION=446&LA=102&nbc=1&q=dht22}
\item \url{https://www.reichelt.de/led-3-mm-bedrahtet-gruen-125-mcd-25--evl-1224-10sygc-p230786.html?&trstct=pol_1&nbc=1}
\item \url{https://www.reichelt.de/led-3-mm-bedrahtet-rot-400-mcd-20--evl-1224-10surc-p230785.html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}
\item \url{https://www.conrad.ch/de/p/stannol-hs10-2510-loetzinn-bleifrei-spule-sn99-3cu0-7-250-g-1-mm-588435.html}
\item \url{https://www.reichelt.com/experimentier-steckboard-640-200-kontakte-steckboard-1k2v-p67678.html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}
\item \url{https://www.reichelt.com/40pol-stiftleiste-gewinkelt-rm-2-54-sl-1x40w-2-54-p19507.html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}
\item \url{https://www.reichelt.com/europlatine-epoxyd-verzinnt-160x100-mm-re-200lf-p53280.html?&trstct=pol_12&nbc=1}
\item \url{https://www.microspot.ch/de/spielwaren-drohnen/drohnen-rc-modellbau/rc-elektronik-werkstatt--c819100/delock-schrumpfschlauch-86264--p0002401137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}
\item \url{https://www.amazon.de/Elektrischer-Silikon-Draht-verschiedene-Isolierter-Temperaturbest%C3%A4ndigkeit/dp/B07G712KWJ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}
\item \url{https://www.digitec.ch/de/s1/product/arduino-uno-atmega328-entwicklungsboard-kit-5764177?supplier=3013528}
\end{enumerate}
\newpage
\section*{Zeitplan}
\input{/home/ugur/Desktop/HS21/gantt/Gantt}
\end{document}

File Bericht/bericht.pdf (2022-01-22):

# Report aus dem Projekt sensor Cube

## von Ugur Turhal, Berkan Kurt & Silvan Lenzlinger

## 22. Januar 2022

Zusammenfassung

Dieses Report Dokument ist im Rahmen der Vorlesung, Rechenarchitektur & vertrauenwurdiges ¨ Rechnen entstanden. Das Ziel war ein 4 x 4 x 4 Kubus zu loten. Diesen mit einem digitalen Luftfeuchtigskeits- ¨ & Temperatursensor zu verbinden. Dieser soll anhand der idealen Luftfeuchtigkeit und der richtigen Temperatur, fur den Schlaf, erreicht ist, spezifische Muster ausgeben. ¨

## 1 Einleitung

Als wir im November uns als Team zusammengesetzt haben war die Mission sofort klar. Wir wollten
mit dem Projekt etwas schaffen, welches uns im alltaglichen Leben auch ¨ | uber den Projektzeitraum hin- ¨
aus, begleiten soll. Nach reichlicher Uberlegung entschieden wir uns f ¨ | ur das Oberthema Schlaf. Wir ¨
haben den Schlaf gewahlt, weil uns aufgefallen ist, dass wir alle drei unseren Schlaf als minderwer- ¨
tig beurteilen. Als wir uns uber die Ursachen und Gr ¨ | unde f ¨ | ur unseren schlechten Schlaf ausgetauscht ¨
haben, kamen wir zum Entschluss, dass wir uns mit der Optimalen Raumtemperatur nie auseinandergesetzt haben. Diese ist vor allem im Winter wichtig, da die Raumtemperatur sich zu dieser Jahreszeit
oftmals uber der optimalen Raumtemperatur, bedingt durch das ¨ | Uberheizen, befindet. Im Nachfolgen- ¨
den Report werden wir daruber reden, wie wir ein Gadget erstellt haben, welches uns hilft, dieses ¨ Problem zu losen. ¨

## 2 Aufteilung

## 3 Jigs/Werkzeuge

Als Jigs werden Hilfsmittel bezeichnet, die beim Prozess des Fertigstellen das Leben vereinfachen.

- Ein Raster aus Holz, in welcher die LEDs reingestellt wurden und verlotet wurden. ¨
- Ein Holzbrett mit welchem die Anode und Kathode in die notige formgebracht wurden. ¨
- Eine Bohrmaschine, welche das Kupferdraht gerade Gewickelt hat.
- Ein Gerat das den Kupferdraht hielt. ¨

Die folgenden Werkzeuge wurden fur die Kommunikation und als Austausch verwendet. ¨

- GitHub, sorgte fur einen Reibungslosen Code und einen Austausch. ¨
- WhatsApp, auf welchem die Meetings festgelegt wurden.
- Zoom, bei Meetings, wenn jemand nicht Anwesend war oder fur Diskussion. ¨
- LATEX dort wurden alle Dokumente erfasst.

## 4 Sammeln der Daten

Bevor das Projekt begann hat Ugur, fur die Sicherstellung des Projektes den Sensor ausgelesen mit ¨ einem externen Programm mittels Python die Raumtemperatur gesammelt und geplotet dieses Findet man PATH. Da der Sensor in einer bestimmten Zeit eine Reaktion zeigen sollte wenn man Luftet und ¨
dann entsprechende Lampchen angehen sollten wurde dies gemacht. Dies diente f ¨ | ur alle als Sicherstel- ¨
lung damit wir einen Sensor hatten so das alles richtig Lauft. Die Untenstehenden Resultate ¨

Daten


Abbildung 1: Plot des Temperatur Anstiegs und der Abfall


Abbildung 2: Scatter Plot des Temperatur Abfalls


Abbildung 3: HIGH und LOW in einem ersten Test

Erkenntnisse durch die Daten In der Abbildung 1 und der Abbildung 2 Sieht man wie uber eine ¨ Gewisse Zeit bei offenen Fenster die Temperatur sinkt. Sommit hatten wir gewissheit, dass der Sensor relativ schnell reagiert und zu gebrauchen ist fur das Projekt. In der Abbildung 3 Sieht man zwei Lichter ¨ Grune und Rote, sobald die Temperatur unter 18 ¨

◦C das die Grune LED auf HIGH war und die Rote ¨ LED auf LOW war, was das Signal ist das die Bedigung fur das Einschlafen erreicht ist. Sobald die ¨ Temperatur wieder auf 18 ◦C war, nach dem Schliessen des Fensters war die Grune LED auf LOW und ¨ die Rote LED auf HIGH. Das war die Bestatigung dass das Konzept, welches wir umsetzen wollten ¨ aufgehen musste.

## 5 Umsetzung


## 6 Resultat

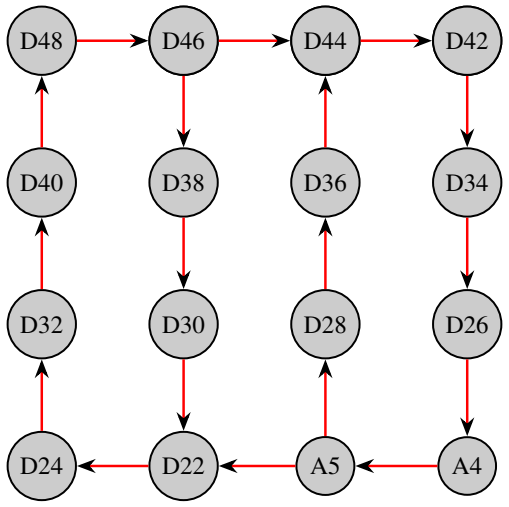
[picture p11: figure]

## 7 Evaluation des Resultats

## 8 Gewonnene Erkentnisse

Dieser Abschnitt besteht nicht nur aus einer Erkenntnis sondern mehreren Erkenntnissen. Deshalb soll in vier Abschnitten folgende Erkentnisse angesprochen werden:

1. Die Fahigkeit beziehungsweise die N ¨ | utzlichkeit unseres Kubus im Alltag, ¨
2. Erkenntnisse uber das verwendete Material, ¨
3. Zeitmanagement bis zur Abgabe,
4. Verbesserung in einem nachsten Projekt. ¨
Nutzlichkeit im Alltag ¨ | Das unser Kubus im Stande ist auf unterschiedlichliche Temperaturen und
eine veranderte Luftfeuchtigkeit zu reagieren ist ausser Frage. Dies wurde in einem Praxistest bei allen ¨ drei Gruppenmitgliedern zu Hause getestet. Das bei einer spezifischen Luftfeuchtigkeit & Temperatur spezifische festgelegte Muster als Feedback angezeigt werden sollen ist vorhanden.
Ugur hat sich per E-Mail mit, Schlafprofessor Prof. Dr. Bjorn Rasch in Kontakt gesetzt, um zus ¨ | atzliche ¨
Informationen uber die optimale Schlaftemperatur und Luftfeuchtigkeit zu erhalten. Aus einer E-Mail ¨ von 03.01.22 wurden drei Punkte deutlich.
1. Der Schlaf steht in Korrelation mit der psychologischen Verfassung des Benutzers des Kubus.
2. Die Temperatur fur den optimalen Schlaf h ¨ | angt von dem Microklima unter der Decke ab. ¨
3. Verschiedene Studien kommen zum Schluss, dass 30-50% oder 30-60% Luftfeuchtigkeit optimal sind.

Punkt eins soll keine Stellung genommen werden, da wir uber keine fundierte psychologische Ausbil- ¨
dung verfugen, selbst wenn das der Fall w ¨ | are, w ¨ | urde dies den Rahmen des Reports sprengen. ¨
Punkt zwei, wir sind sicherlich derselben Meinung, wenn eine Decke zu warm ist, dass der Schlaf dadurch beeintrachtigt wird. Unser Kubus hat aber bei allen drei Mitgliedern dieselbe Erkenntnis her- ¨
vorgerufen, selbst wenn das Microklima unter der Decke mit der Zeit sich andert, durch das L ¨ | uften ¨
in dieser kalten Jahreszeit, das als Konsequenz eine niedrigere Raumtemperatur hervorruft, fallt das ¨ Einschlafen mit dem Kubus, bei allen drei Gruppenmitgliedern einfacher.
Punkt drei, dass die Luftfeuchtigkeit stimmen muss fur den Schlaf/Einschlaf, vorallem in einer kalten ¨ Jahreszeit, da kalte Luft relativ trocken ist, kann unser Kubus auch evaluieren.

Fazit Die Benutzung des sensor Cubes kann hilfreich sein beim Einschlafen. Allen drei Gruppenmitgliedern hat der sensor Cube aber geholfen.

Das verwendete Material Folgende Komponenten wurden verwendet:

1. Kupferdraht
2. Kabel mit einer Litze
3. Arduino UNO 328P → Arduino ATMega 2560
4. Lotzinn ¨
5. Flussmittel
6. Schrumpfschlauch
7. Euro-Platine aus Epoxidharz
8. Plexiglas
9. Lot-Station ¨
10. DHT-22
11. LEDs
12. Scharniere
13. Sekundenkleber
14. USB-Stecker - Typ B
15. Multimeter
16. Heissluftfohn ¨
17. Bohrmaschine

In dieser Tabelle sollen nur die Teile aufgelistet werden, welche Probleme bereitet haben. Die Komponenten die nicht in der Tabelle sind, haben keine Probleme verursacht.

Zeitmangement Da wir einen Strikten Gant-Chart befolgt haben, wurde alles in der Zeiterledigt, in der denen es zu erreichen war. Wir haben vor dem 1. Januar 2022 genauer am 31.Dezember 2021, ,mit dem sensor Cube fertig. Somit konnten wir viel testen und uns zusatzliche Gedanken machen. ¨ Wie zum Beispiel, sollen wir die Luftfeuchtigkeit zusatzlich beachten? Wollen wir ein Case machen? ¨ Welche Feedbacks wollen wir? Was ist Sinvoll als Feedback zu nehmen? Wir konnen behaupten, dass ¨ wir die Verwendung des Gant-Charts nochmal in ein selbes Projekt einbinden wurden, da dieses den ¨
Zeitplan relativ gut eingeteilt hat und immer wieder Uberpr ¨ | ufen konnten wo stehen wir. ¨
Verbesserungswurdig ¨ | Verbesserungswurdig ist in jedem Falle, in einem n ¨ | achsten Projekt, dass ¨
wir durch den Angesprochenen Zeitpuffer, im Paragraph Zeitmangement, vorher definieren wurden, ¨ ob wir ein Case wollen, welche Materialien verwendet werden sollen. Silvan und Berkan tendieren
beide zu Holz, was das Budget erhohen k ¨ | onnte, aber einfacher w ¨ | are das in diesem Projekt einzubinden. ¨
Ugur ist der Meinung Plexiglas sieht besser aus, er wurde sich einen anderen Klebstoff suchen. Zu dem ¨
wurden wir uns vorher gedanken machen ob wir genug Pins zur Verf ¨ | ugung stehen, das hat uns zwei ¨
Tage gekostet, da die Lieferung bisschen verzogert war. ¨

## 9 Danksagung

Folgenden Personen/ dem Arbeitgeber soll gedankt werden:
Frau Sarah-Lia Andrea Wotke, sie hat Ugur eine Einfuhrung in das L ¨ | oten gegeben, er konnte sein ¨
Wissen mit Berkan und Silvan teilen. Zu dem hat Sie wichtige Tips gegeben, wir die Kabel isolieren.
Herr Prof. Dr. Bjorn Rasch ¨ | an der Universitat Fribourg, er hat dem Projekt eine andere Sichtweise ¨
gegeben und was beachtet werden sollte.
Herr Ilir Ferati Welcher wichtige Tipps gegeben hat beim Bau des Case und als Ratschlag mitgegeben
hat, bitte nachstes Mal Entscheidungen ob ihr ein Case wollt oder nicht fr ¨ | uher vor dem Fertigstellen ¨
des Kubus fallen. ¨
Als letztes wollen wir uns bei der Abteilung Technik des Telebasels Danken, diese hat uns mit der
Zurverfugung Stellung eines Funktionsf ¨ | ahigen L ¨ | otkolbens unseren Zeitplan sichergestellt. ¨

Tabelle 1: Probleme und Losungen ¨
Komponente | Problem | Losung ¨
Kupferdraht | Der Kupfer draht, welcher be-
stellt wurde, war beschichtet und ohne das Lotzinn drauf war die- ¨ ser nicht Leitfahig, die Schicht ¨
musste | geschmolzen | werden
oder abgeschliffen werden

Neuer Kupferdraht wurde erworben

Arduino | Da wir alle LEDs einzeln ansteu- ern wollten aber auch den Sensor Verbauen mussten, mussten wir entweder mit i2c arbeiten oder mehr Pins haben

Ugur entschied sich im Sinne der Gruppe auf einen Arduino AT-Mega 2560 umzustellen

Lotzinn ¨ | Der Lotzinn, welcher mitgege- ¨ ben wurde, war relativ alt und er- gab beim ersten Loten Zinnku- ¨ geln, was optisch nicht anspre- chend war
Flussmitttel wurde erworben
Schrumpfschlauch | Der Schrumpfschlauch der Er-
worben wurde, passte nicht auf die Verbingdungskabel
Schrumpfschlauch | mit | 3mm,
welcher auf eine grosse von ¨ 1mm schrumpfte wurde Erworben
Euro-Platine aus Epoxidharz | Bis heute sind wir in der Grup-
pe nicht einig ob wir die Euro-Platine anders herum hatten ver- ¨ wenden sollen, da der Lotzinn ¨ nicht haftete

Plexiglas | Wir wollten nicht nur ein Platz fur unseren Arduino, sondern ¨ auch ein Case fur den Kubus aus ¨ Plexiglas, leider reflektierte das Material die Lichter der LEDs zu stark, somit war nicht erkennbar welche LED rot oder Grun leuch- ¨ tete.

Verzicht den Kubus in ein Plexiglas gehause zu stellen. ¨

Lot-Station ¨ | Die Lot-Spitze, welcher mitge- ¨
geben wurde, war oxidiert, somit war es nicht moglich mit ¨
dieser Lot-Station zu l ¨ | oten, ent- ¨
weder musste die Lotspitze ge- ¨ reinigt werden oder eine andere Lotstation musste her. ¨

Ugurs Arbeitgeber verlieh eine Professionelle Lot-Station aus. ¨

DHT-22 | Ein Sensor der Mitgelifiert wur- de, war defekt. Da wir aber aus Sicherheitsgrunden und berich- ¨ ten zwei bestellt hatten hatten wir ein Backup

Der zusatzliche Sensor wurde ¨ verwendet.

Sekundenkleber | Die Kombination aus Sekun-
denkleber und Plexiglas vertragt ¨ sich nicht gut beim ausprobieren hat Berkan festgestellt das Spuren des Klebers sichtbar werden
Berkan | hat | trotz | der | Ein-
schrankung, versucht so sauber ¨ wie moglich zu arbeiten ¨
USB-Stecker - Typ B | Der USB-Stecker Typ B war re- lativ Dick, das wir keine Indus- trie sind, stehen uns nur bedingte Bohrer zu verfugung, das Loch, ¨ welcher fur das Kabel gedacht ¨ ist, ist ein bisschen Eng.

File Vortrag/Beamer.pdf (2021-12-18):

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

sleepCube

Ugur Turhal,
Silvan
Lenzlinger &
Berkan Kurt

Projekt Idee

sleepCube -
INFOS

Mögliche
Schwierigkeiten

Timeline

Fragen

Mögliche Schwierigkeiten
- Sauberes Löten
- Symmetrischer Cube z.B. Abstände
- Ästhetik
- Gestell (Gehäuse z.B. aus Plexiglas)
- Digitaler Temperatur Sensor (Noch nie benutzt)

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

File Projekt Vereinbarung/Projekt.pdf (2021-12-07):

Projekt sleepCube
CatcHS21

Silvan Lenzlinger
Berkan Kurt
Ugur Turhal

Zusammenfassung

Das Projekt, sleepCube, ist ein 4 x 4 x 4 Arduino LED-cube. Dieser LED-cube ist mit einem DHT22 Sensor ausge-stattet. Dieser Sensor kann die Luftfeuchtigkeit und die Temperatur messen. Fur das Projekt ist die letztere Funktion ¨ von relevanz.

Ziel des Projektes

Das Endprodukt, soll als Nachttischlampe dienen, welche anzeigt ob eine angehneme Raumtemperatur fur ¨ das Schlafen vorhanden ist oder nicht. Diese ¨angehneme Raumtemperatur fur das Schlafen”wird mit zwei ¨ Farben angezeigt:

(a) ROT fur eine nicht angehme Schlafenstemperatur: ¨
<(15 - 18)◦C oder > (15 - 18)◦C
(b) GRUN¨ fur eine angehme Schlafenstemperatur: ¨ (15 - 18)◦C

Mitglieder

Im Projekt involviert sind folgende Personen:

(1) Silvan Lenzlinger
(2) Berkan Kurt
(3) Ugur Turhal

Komponenten und Kosten

Fur das Projekt ben ¨ | ¨otigte Komponenten, sowohl die Kosten der Komponenten:
Komponenten | Anzahl | CHF
Arduino Uno ATMega 328 | 1 | 24.94 | 24.94
EVL 1224-10SURC LED, 3 mm, bedrahtet, rot, 400 mcd, 20◦ | 40 | 0.20 | 8
EVL 1224-10SYGC LED, 3 mm, bedrahtet, grun, 125 mcd, 25 ¨
- | 40 | 0.20 | 8
Widerstand 220Ω | 8 | 0.15 | 1.2
28 AWG Elektrischer Draht 13m | 1 | 18.50 | 18.5
DELOCK Schrumpfschlauch 86264 | 1 | 6.40 | 6.4
Stannol HS10 2510 L¨otzinn, bleifrei Spule Sn99,3Cu0,7 250 g 1 mm | 1 | 18.15 | 18.15
SL 1X40W 2,54 40pol. Stiftleiste, gewinkelt, RM 2,54 | 5 | 0.40 | 2
RE 200LF Europlatine, Epoxyd, verzinnt 160x100 mm | 1 | 6.90 | 6.9
DEBO DHT 22 Entwicklerboards - Temperatur- & Feuchtigkeitssensor, DHT22 | 2 | 6.00 | 12
STECKBOARD 1K2V Experimentier-Steckboard 640/200 Kontakte | 1 | 6.50 | 6.5
MagiDeal USB A Male to Female Extenstion Kabel mit Switch On/Off | 1 | 3.96 | 3.96
TOTAL | 0 | 0 | 0116.55

1

Projekt sleepCube
CatcHS21

Silvan Lenzlinger
Berkan Kurt
Ugur Turhal

Links zu den Websiten

(a) https://www.reichelt.de/de/de/widerstand-kohleschicht-220-ohm-0207-250-mw-5--1-4w-220-p1382.html?r=1 (https://www.reichelt.de/de/de/widerstand-kohleschicht-220-ohm-0207-250-mw-5--1-4w-220-p1382.html?r=1)
(b) https://www.amazon.de/MagiDeal-Female-Extenstion-Kabel-Switch/dp/B01IP1HDUU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 (https://www.amazon.de/MagiDeal-Female-Extenstion-Kabel-Switch/dp/B01IP1HDUU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)
(c) https://www.reichelt.com/ch/de/index.html?ACTION=446&LA=102&nbc=1&q=dht22
(d) https://www.reichelt.de/led-3-mm-bedrahtet-gruen-125-mcd-25--evl-1224-10sygc-p230786.html?&trstct=pol_1&nbc=1 (https://www.reichelt.de/led-3-mm-bedrahtet-gruen-125-mcd-25--evl-1224-10sygc-p230786.html?trstct=pol_1&nbc=1)
(e) https://www.reichelt.de/led-3-mm-bedrahtet-rot-400-mcd-20--evl-1224-10surc-p230785.html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 (https://www.reichelt.de/led-3-mm-bedrahtet-rot-400-mcd-20--evl-1224-10surc-p230785.html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)
(f) https://www.conrad.ch/de/p/stannol-hs10-2510-loetzinn-bleifrei-spule-sn99-3cu0-7-250-g-1-mm-588435. html (https://www.conrad.ch/de/p/stannol-hs10-2510-loetzinn-bleifrei-spule-sn99-3cu0-7-250-g-1-mm-588435.html)
(g) https://www.reichelt.com/experimentier-steckboard-640-200-kontakte-steckboard-1k2v-p67678.html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 (https://www.reichelt.com/experimentier-steckboard-640-200-kontakte-steckboard-1k2v-p67678.html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)
(h) https://www.reichelt.com/40pol-stiftleiste-gewinkelt-rm-2-54-sl-1x40w-2-54-p19507.html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 (https://www.reichelt.com/40pol-stiftleiste-gewinkelt-rm-2-54-sl-1x40w-2-54-p19507.html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)
(i) https://www.reichelt.com/europlatine-epoxyd-verzinnt-160x100-mm-re-200lf-p53280.html?&trstct=pol_12&nbc=1 (https://www.reichelt.com/europlatine-epoxyd-verzinnt-160x100-mm-re-200lf-p53280.html?trstct=pol_12&nbc=1)
(j) https://www.microspot.ch/de/spielwaren-drohnen/drohnen-rc-modellbau/rc-elektronik-werkstatt--c819100/delock-schrumpfschlauch-86264--p0002401137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 (https://www.microspot.ch/de/spielwaren-drohnen/drohnen-rc-modellbau/rc-elektronik-werkstatt--c819100/delock-schrumpfschlauch-86264--p0002401137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)
(k) https://www.amazon.de/Elektrischer-Silikon-Draht-verschiedene-Isolierter-Temperaturbest%C3%A4ndigkeit/dp/B07G712KWJ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 &adgrpid=61057452133&hvpone=&hvptwo=&hvadid=308445120684&hvpos=&hvnetw=g&hvrand=1935893886139910953& hvqmt=&hvdev=m&hvdvcmdl=&hvlocint=&hvlocphy=1003297&hvtargid=pla-530392830435 (https://www.amazon.de/Elektrischer-Silikon-Draht-verschiedene-Isolierter-Temperaturbest%C3%A4ndigkeit/dp/B07G712KWJ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)
(l) https://www.digitec.ch/de/s1/product/arduino-uno-atmega328-entwicklungsboard-kit-5764177?supplier=3013528 (https://www.digitec.ch/de/s1/product/arduino-uno-atmega328-entwicklungsboard-kit-5764177?supplier=3013528)

2

Projekt sleepCube
CatcHS21

Silvan Lenzlinger
Berkan Kurt
Ugur Turhal

Zeitplan

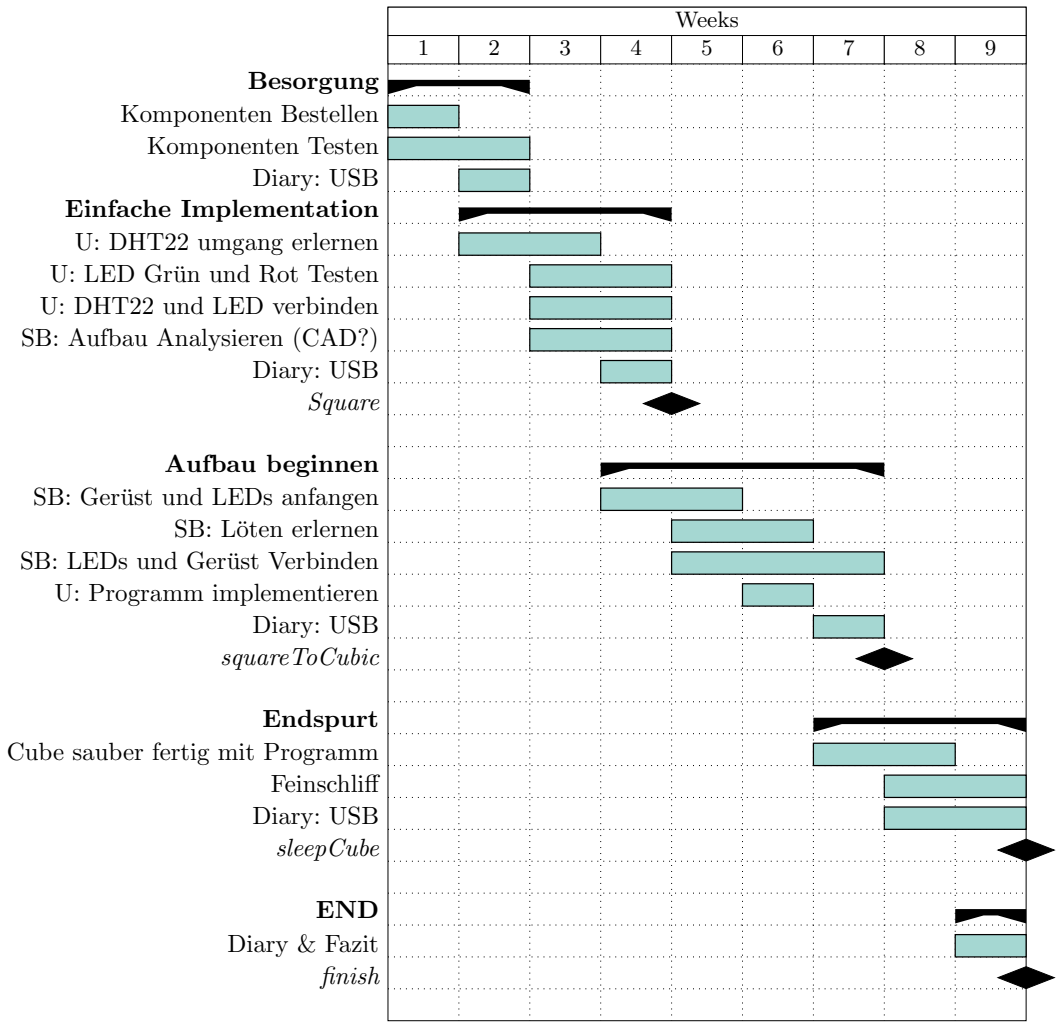
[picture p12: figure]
Weeks; Besorgung Komponenten Bestellen Komponenten Testen Diary: USB Einfache Implementation U: DHT22 umgang erlernen U: LED Grun und Rot Testen ¨ U: DHT22 und LED verbinden SB: Aufbau Analysieren (CAD?) Diary: USB Square; Aufbau beginnen SB: Gerust und LEDs anfangen ¨ SB: L¨oten erlernen SB: LEDs und Gerust Verbinden ¨ U: Programm implementieren Diary: USB squareToCubic; Endspurt Cube sauber fertig mit Programm Feinschliff Diary: USB sleepCube; END Diary & Fazit finish

Fig. 1: Ganttchart Project: sleepCube

3

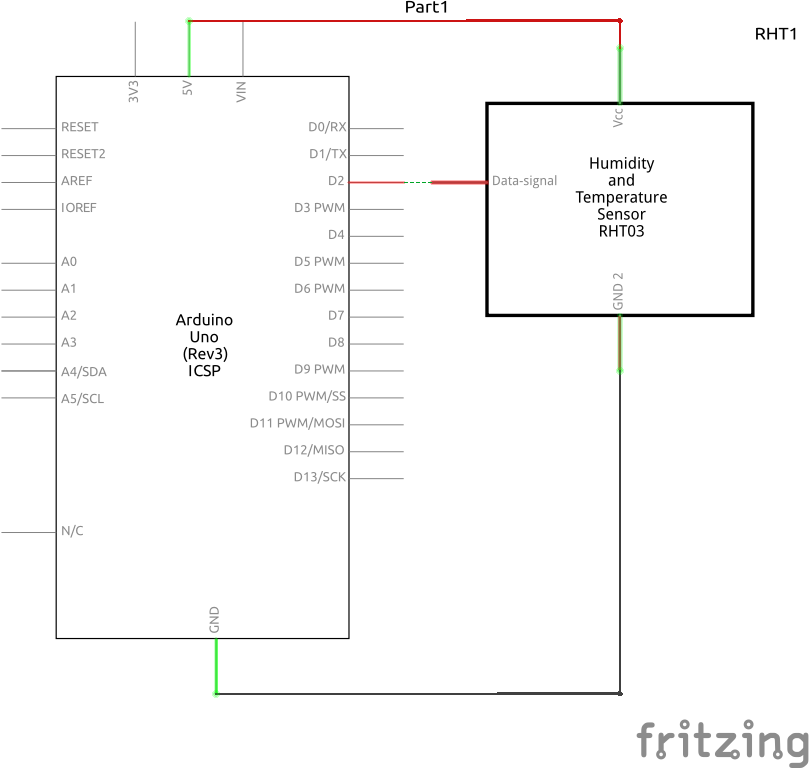
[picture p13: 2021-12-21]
Aufbau DHT, Programme und Daten/pics/pics/schematic.png

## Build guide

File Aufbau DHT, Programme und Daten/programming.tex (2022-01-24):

\documentclass[12pt]{article}
\usepackage[letterpaper,left=4.9cm,right=1.9cm,top=3.1cm,bottom=2.3cm]{geometry} % Márgenes y demás
\usepackage[nswissgerman]{babel}
\usepackage{siunitx}
\usepackage[table]{xcolor}
\usepackage{dirtree}
\usepackage{pythonhighlight}
\input{Styles_ACCEFN.sty}  

\setlength{\topskip}{0.5cm}
\setlength{\parindent}{0mm}

%\title{\fontsize{14}{14}\textbf{Sleep Cube - Diary} \\[0.2cm]

\title{\textcolor{gray}{\textbf{sleepCube - Programme/Aufbau}\\[0.2cm]}}

\author[1]{\fontsize{9}{9} \textbf{Ugur Turhal}}

\affil[1]{\fontsize{8}{8}\href{mailto:ugur.turhal@me.com}{ugur.turhal@me.com}}
\date{\today}                     
\setcounter{Maxaffil}{0}

\usepackage{listings,newtxtt}

\lstset{basicstyle=\ttfamily, keywordstyle=\bfseries}    

\definecolor{mygreen}{rgb}{0,0.6,0}
\definecolor{mygray}{rgb}{0.47,0.47,0.33}
\definecolor{myorange}{rgb}{0.8,0.4,0}
\definecolor{mywhite}{rgb}{0.98,0.98,0.98}
\definecolor{myblue}{rgb}{0.01,0.61,0.98}

\lstnewenvironment{code}{\lstset{ %
  backgroundcolor=\color{mywhite},   
  basicstyle=\footnotesize,       
  breakatwhitespace=false,         
  breaklines=true,                 
  captionpos=b,                   
  commentstyle=\color{mygray},    
  deletekeywords={...},           
  escapeinside={\%*}{*)},          
  extendedchars=true,              
  frame=shadowbox,                    
  keepspaces=true,                 
  keywordstyle=\color{myorange},       
  language=C++,                
  morekeywords={*,...},            
  numbers=left,                    
  numbersep=5pt,                   
  numberstyle=\tiny\color{mygray}, 
  rulecolor=\color{black},         
  rulesepcolor=\color{myblue},
  showspaces=false,                
  showstringspaces=false,          
  showtabs=false,                  
  stepnumber=2,                    
  stringstyle=\color{myorange},    
  tabsize=2,                       
  title=\lstname                   
}}{}

\DeclareSIUnit \volt{V} %apparent power 
\begin{document}
\maketitle
\tableofcontents
\addtocontents{toc}{\protect\thispagestyle{empty}}
\newpage
\setcounter{page}{1}
\section{DHT22}
\justifying
Der Sensor ist ein DHT22, welcher wie folgt aus sieht. Mit diesem wird die Umgebungstemperatur gemessen. Der DHT22 hat 4 Pins siehe Bild \ref{Fig:description}. Dessen Erläuterung ist in der Tabelle\ref{Tabular:pins}.
\begin{figure}[H]
\begin{center}
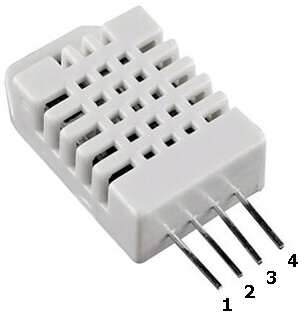
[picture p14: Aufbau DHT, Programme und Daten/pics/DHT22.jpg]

\caption{DHT22 - Pins}
\label{Fig:description}
\end{center}
\end{figure}
\subsection{Pins und deren Bedeutung}
\begin{table}[H]
\centering
\rowcolors{2}{purple!30}{pink!60}
\begin{tabular}{l|l}
\textbf{Pin} & \textbf{Funktion}\\ \hline \hline
1 & Betriebsspannung (3,3V - 5,5V) \\ \hline
2 & Serial Data Line\\\hline
3 & Nicht belegt\\ \hline
4 & Ground
\end{tabular}
\caption{Pins - Bedeutung}
\label{Tabular:pins}
\end{table}
\subsection{Verkabelung}
\begin{figure}[H]
\begin{center}
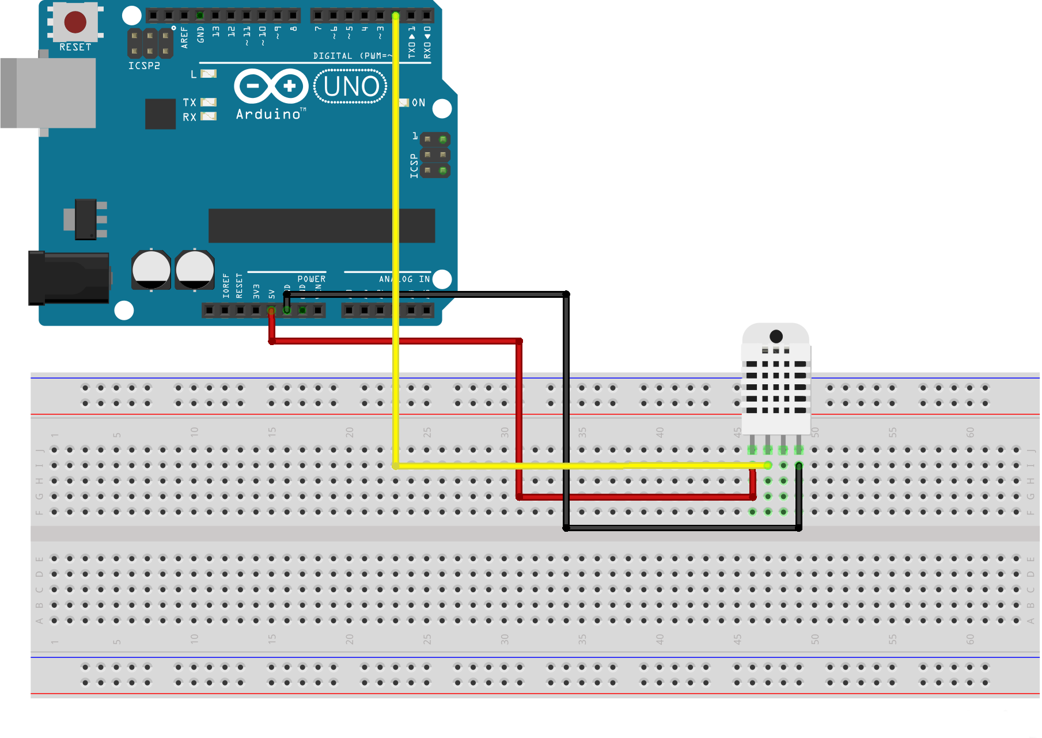
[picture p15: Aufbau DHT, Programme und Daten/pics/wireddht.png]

\caption{DHT mit Arduino UNO verbunden}
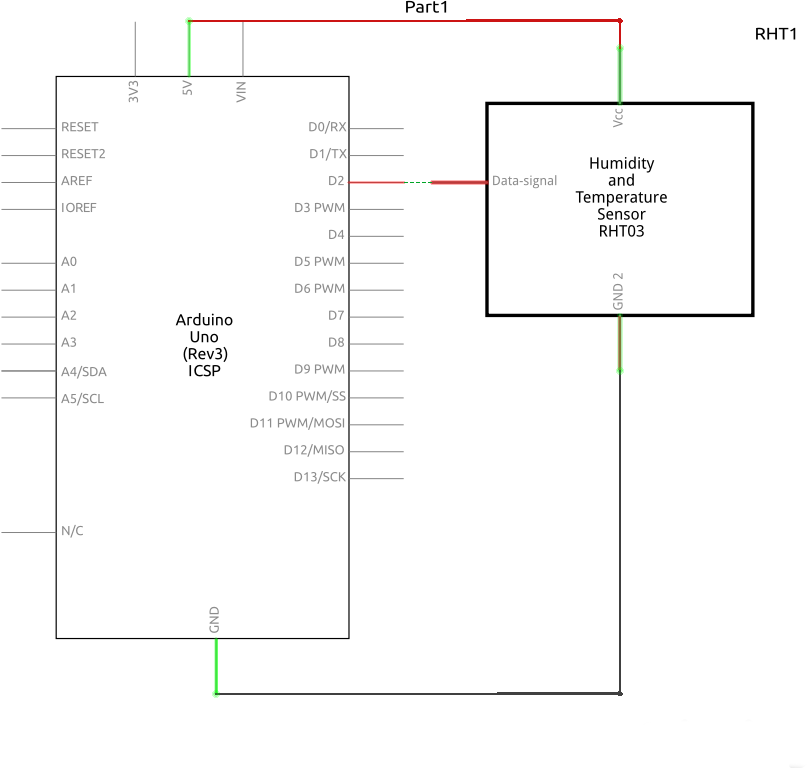
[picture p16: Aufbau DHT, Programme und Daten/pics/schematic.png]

\caption{Schaltplan DHT22 und Arduino UNO}
\end{center}
\end{figure}
\section{DHT22 - Arduino}
\justifying
Installiere die DHT sensor library in die Arduino IDE:
\begin{figure}[H]
\DTsetlength{0.2em}{2.5em}{0.2em}{0.4pt}{2.6pt}
\dirtree{%
.1 /.
.2 Tools.
.3 Manage Libraries$\dots$ .
.4 Mangae Library.
.5 \textit{Filter your Search}.
.6 DHT22.
.6 \textbf{DHT22 sensor library}\\ by Adafruit Version 1.4.3.
}
\end{figure}
%%%%%%%%%%%%%%%%%%%%%%%%%%%%%%%%%%%%%%%%%%%%%%%%%%%%%%%%%%%%%%%%%%%%%%%%%%%%%%%%%%%%%%%%%%%%%%%%%%%%%%%%%%%%%%%%%%%%%%%%%%%%%%%%%%%%%%%%%%%%%%%%%%%%%%%%%%%%%%%%%%%%
DHT22 ist bereit zum Einsatz.

\subsection{Arduino Code}
\begin{code}
#include "DHT.h"

#define DHTPIN 2 //Pin Nummer wo der Sensor angeschlossen ist
#define DHTTYPE DHT22 //Definition was fuer ein Sensor ausgelesen wird.

DHT dht(DHTPIN, DHTTYPE);

void setup() {
  // put your setup code here, to run once:
  Serial.begin(9600);
  //Serial.println("DHT22 Testprogramm");
  dht.begin();

}

void loop() {
  delay(2000);                     
                                    
  float h = dht.readHumidity();    
  float t = dht.readTemperature();
  
  if (isnan(h) || isnan(t)) {       
    Serial.println("Fehler beim auslesen des Sensors!");
    return;
  }

  Serial.print(h);                 
  Serial.print(" ");                          
  Serial.println(t);
}
\end{code}
\newpage
\subsection{Python and Arduino}
Zwei Python Programme wurden geschrieben um Daten aufzunehmen und zu visualisieren.
\begin{python}[language=Python]
# @author Ugur Turhal
# This python file reads the serial port of the Arduino and gives a live plot
import serial
import time
import csv
import matplotlib
import matplotlib.pyplot as plt
import numpy as np

matplotlib.use("tkAgg")
ser = serial.Serial('/dev/ttyACM0')
ser.flushInput()

plot_window = 360
y_var = np.array(np.zeros([plot_window]))
plt.ion()
fig, ax = plt.subplots()
ax.grid(linestyle="--")
ax.set_ylabel("Celsius")
ax.set_xlabel("x")
ax.set(xlabel='x', ylabel='Celsius',
       title='Increase & Decrease of \n Temperature')
line, = ax.plot(y_var)

while True:
    try:
        ser_bytes = ser.readline()
        try:
            decoded_bytes = ser_bytes[0:len(ser_bytes) - 2].decode("utf-8")
            print(decoded_bytes)
        except:
            continue
        with open("test_data.csv", "a") as f:
            writer = csv.writer(f, delimiter=",")
            writer.writerow([time.time(), decoded_bytes])
        y_var = np.append(y_var, decoded_bytes)
        y_var = y_var[1:plot_window + 1]
        line.set_ydata(y_var)
        ax.relim()
        ax.autoscale_view()
        fig.canvas.draw()
        fig.canvas.flush_events()
        fig.savefig('full_figure.png')
    except:
        print("Stopped")
        break
\end{python}
\newpage
\begin{python}
# @author Ugur Turhal
# This python skript reads a CSV file, which
# is filtered and Plots in a log Plot the temperature

import numpy as np
import pandas as pd
import matplotlib.pyplot as plt

plt.style.use('seaborn')

def main():
    df = pd.read_csv("groupeddata.csv", usecols=['Measurement', 'Temperature']).drop_duplicates(keep='first').reset_index()
    measurement = df['Measurement']
    temperature = df['Temperature']
    df.to_csv("cleanData.csv");
    colors = [1, 2, 3, 4, 5, 6, 7, 8, 9, 10, 11, 12, 13, 14, 15, 16, 17, 18, 19, 20, 21, 22, 23, 24, 25, 26, 27, 28, 29, 30, 31, 32, 33, 34, 35, 36, 37, 38, 39, 40, 41, 42, 43, 44, 45, 46, 47, 48, 49, 50, 51, 52, 53, 54, 55, 56, 57, 58, 59, 60, 61, 62, 63, 64, 65, 66, 67, 68, 69, 70, 71, 72, 73, 74, 75, 76, 77, 78, 79, 80, 81, 82, 83, 84, 85, 86, 87, 88, 89, 90]

    plt.scatter(x=measurement, y=temperature, s=25, c=colors, alpha=0.6, edgecolor='black', linewidth=1,
                    cmap='Blues_r')

    cbar = plt.colorbar()
    cbar.set_label('Mesurements with Temperature')
    plt.xscale('log')
    plt.yscale('log')
    plt.title('Scatter of Temperature')
    plt.xlabel('Measurement')
    plt.ylabel('Temperature')

    plt.savefig("data.png")
    plt.show()

if __name__ == "__main__":
    print(main())

\end{python}
\subsection{Plots}
Für die Erklärung siehe: \url{https://github.com/ugurtu/CatcProject/blob/main/Bericht/bericht.pdf}
\begin{figure}[H]
\begin{center}

\caption{Temperaturausgaben über eine bestimme Zeit}

\caption{Einzelne Messpunkte des DHT22}
\end{center}
\end{figure}
\newpage
\section{Simples Modell}
Arduino:
\begin{code}
#include "DHT.h"

#define DHTPIN 2 //Pin Nummer wo der Sensor angeschlossen ist
#define DHTTYPE DHT22 //Definition was fuer ein Sensor ausgelesen wird.
#define pinRed 4 // LEDPin4
#define pinGreen 5 //LEDPin5

DHT dht(DHTPIN, DHTTYPE);

void setup() {
  // put your setup code here, to run once:
  Serial.begin(9600);
  //Serial.println("DHT22 Testprogramm");
  pinMode(pinRed, OUTPUT);
  pinMode(pinGreen, OUTPUT);

  dht.begin();

}

void loop() {
  delay(2000);

  float h = dht.readHumidity();
  float t = dht.readTemperature();

  if (isnan(h) || isnan(t)) {
    Serial.println("Fehler beim auslesen des Sensors!");
    return;
  }

  if (t >= 15.00 && t <= 18.00) {
    digitalWrite(pinRed, LOW);
    digitalWrite(pinGreen, HIGH);
  }
  else  {
    digitalWrite(pinGreen,LOW);
    digitalWrite(pinRed, HIGH);    
  }   
   Serial.print(digitalRead(pinRed));
   Serial.print(" ");
   Serial.print(digitalRead(pinGreen));
   Serial.print(" ");
   Serial.println(t);
}
\end{code}
\begin{figure}[H]
\begin{center}
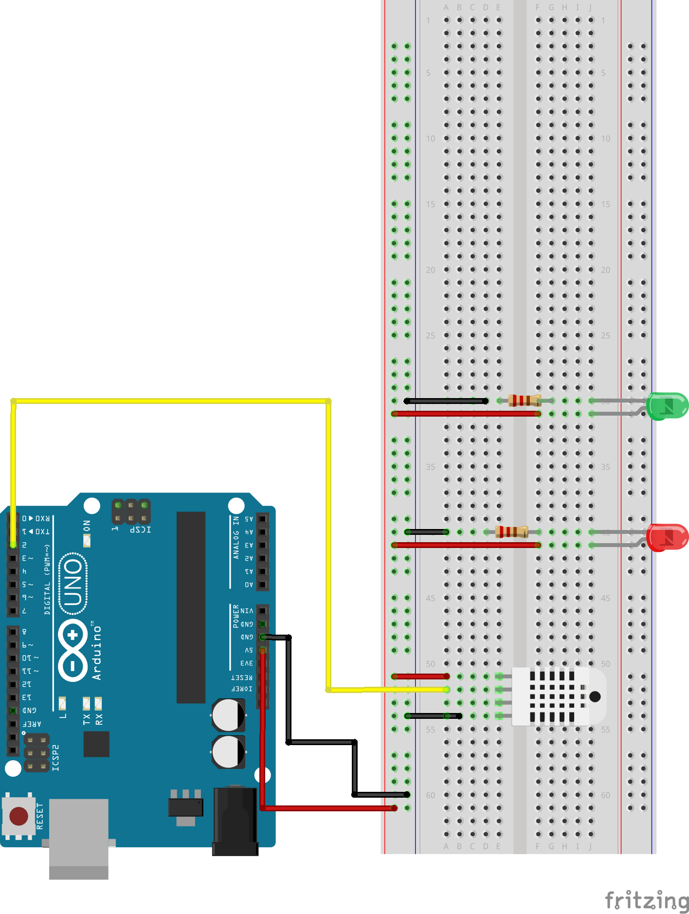
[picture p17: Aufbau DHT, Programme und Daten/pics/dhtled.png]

\caption{DHT und LEDs verbunden an Breadboard mit Arduino}
\end{center}
\end{figure}

\begin{python}
# @author Ugur Turhal

# This python file reads the serial port of the Arduino and
# reads the state of the LEDs out and Shows the Temperature

import numpy as np
import pandas as pd
import matplotlib.pyplot as plt
import serial
import time
import csv
from drawnow import *

plt.style.use('seaborn')
ser = serial.Serial('/dev/ttyACM0')
ser.flushInput()

ledRedPin = []
ledGreen = []
temperature = []

def makeFig():
    plt.close("all")
    plt.title('HIGH and LOW of \n selected pins')
    plt.ylim(0, 1.5, 0.4)
    plt.plot(ledRedPin, label='digitalRead_Red', color='red')
    plt.legend(bbox_to_anchor=(1.0, 0.5), loc='upper left')

    plt2 = plt.twinx()
    plt.ylim(0, 30, 6)
    plt2.plot(temperature, label='C')
    plt2.legend(bbox_to_anchor=(1.0, 1.01), loc='upper left')

    plt3 = plt.twinx();
    plt.ylim(0, 1.5)
    plt3.plot(ledGreen, label='digitalRead_Green', color='green')
    plt3.legend(bbox_to_anchor=(1.0, 0), loc='upper left')

    plt.tight_layout()
    plt.savefig("digitalRead.png")

def main():
    while True:
        ser_bytes = ser.readline()
        while ser.inWaiting() == 0:
            pass
        try:
            r = float(ser_bytes[0:1].decode("utf-8"));
            g = float(ser_bytes[1:len(ser_bytes) - 7].decode("utf-8"));
            temp = float(ser_bytes[3:len(ser_bytes)].decode("utf-8"));
            ledRedPin.append(r)
            temperature.append(temp)
            ledGreen.append(g)
            drawnow(makeFig)
        except:
            continue
            print("ERROR")
        with open("states.csv", "a") as f:
            writer = csv.writer(f, delimiter=",")
            writer.writerow([r, g, temp])

if __name__ == '__main__':
    print(main())

\end{python}
\begin{figure}[H]
\begin{center}

\caption{HIGH und LOW bei bestimmten Temperaturen beim Auslesen des Serial Ports}
\end{center}
\end{figure}
Für die Erklärung der Abbildung 7 siehe: \url{https://github.com/ugurtu/CatcProject/blob/main/Bericht/bericht.pdf}
\end{document}

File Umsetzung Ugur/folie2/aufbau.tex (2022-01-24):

\documentclass[[table,border=3mm]{standalone}
\usepackage{tikz}
\usetikzlibrary{positioning}
	
\usepackage{xcolor}
\definecolor{lightgray}{gray}{0.9}
\begin{document}
\begin{tikzpicture}
\node (figure) at (0,0) {};
\node (tabular)[below = of figure] {\begin{tabular}{l|l}
\textbf{Pin} & \textbf{Funktion}\\ \hline \hline
1 & Betriebsspannung (3,3V - 5,5V) \\ \hline
2 & Serial Data Line\\\hline
3 & Nicht belegt\\ \hline
4 & Ground 
\end{tabular}};
\end{tikzpicture}
\end{document}

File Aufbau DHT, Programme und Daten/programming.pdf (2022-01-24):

## sleepCube - Programme/Aufbau

Ugur Turhal¹

## 1ugur.turhal@me.com

## Inhaltsverzeichnis

1 DHT22 | 1
2 DHT22 - Arduino | 2
3 Simples Modell | 7

## 1 DHT22

## Der Sensor ist ein DHT22, welcher wie folgt aus sieht. Mit diesem wird die Umgebung-stemperatur gemessen. Der DHT22 hat 4 Pins siehe Bild 1. Dessen Erläuterung ist in der

Tabelle1.

## Abbildung 1. DHT22 - Pins


1.1 | Pins und deren Bedeutung
Pin | Funktion
1 | Betriebsspannung (3,3V - 5,5V)
2 | Serial Data Line
3 | Nicht belegt
4 | Ground

## Tabelle 1. Pins - Bedeutung

## 1.2 Verkabelung


## Abbildung 2. DHT mit Arduino UNO verbunden


## Abbildung 3. Schaltplan DHT22 und Arduino UNO

## 2 DHT22 - Arduino

## Installiere die DHT sensor library in die Arduino IDE:

/

### Tools

Manage Libraries...

### Mangae Library Filter your Search DHT22

## DHT22 sensor library

### by Adafruit Version 1.4.3

DHT22 ist bereit zum Einsatz.

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

5
DHT d ht ( DHTPIN , DHTTYPE ) ;

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

13
}

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

## 2.2 Python and Arduino

## Zwei Python Programme wurden geschrieben um Daten aufzunehmen und zu visuali-

sieren.

# @author Ugur Turhal

# This python file reads the serial port of the Arduino and gives a live plot

import serial
import time
import csv
import matplotlib
import matplotlib . pyplot as plt import numpy as np

matplotlib . use (" tkAgg ")
ser = serial . Serial (’/dev/ ttyACM0 ’) ser . flushInput ()

plot_window = 360
y_var = np . array ( np . zeros ([ plot_window ]) ) plt . ion ()
fig , ax = plt . subplots ()
ax . grid ( linestyle =" --")
ax . set_ylabel (" Celsius ")
ax . set_xlabel ("x")
ax .set ( xlabel =’x’, ylabel =’Celsius ’,
| title =’Increase & Decrease of \n Temperature ’)
line , = ax . plot ( y_var )

while True :
| try: ser_bytes = ser . readline () try: decoded_bytes = ser_bytes [0:len( ser_bytes ) - 2]. decode

("utf -8")
| print ( decoded_bytes ) except : continue with open (" test_data .csv", "a") as f: writer = csv . writer (f , delimiter =",") writer . writerow ([ time . time () , decoded_bytes ]) y_var = np . append ( y_var , decoded_bytes ) y_var = y_var [1: plot_window + 1] line . set_ydata ( y_var ) ax . relim () ax . autoscale_view () fig . canvas . draw () fig . canvas . flush_events () fig . savefig (’ full_figure .png ’) except : print (" Stopped ") break

# @author Ugur Turhal

# This python skript reads a CSV file , which

# is filtered and Plots in a log Plot the temperature

import numpy as np
import pandas as pd
import matplotlib . pyplot as plt

plt . style . use (’seaborn ’)

def main ():
df = pd . read_csv (" groupeddata .csv", usecols =[’ Measurement ’, ’ Temperature ’]) .
drop_duplicates ( keep =’first ’) . reset_index ()
measurement = df[’Measurement ’]
temperature = df[’Temperature ’]
df . to_csv (" cleanData .csv ") ;
colors = [1 , 2 , 3 , 4 , 5 , 6 , 7 , 8 , 9 , 10 , 11 , 12 , 13 , 14 , 15 , 16 , 17 , 18 , 19 , 20 , 21 , 22 , 23 , 24 , 25 , 26 , 27 , 28 , 29 , 30 , 31 , 32 , 33 , 34 , 35 , 36 , 37 , 38 , 39 , 40 , 41 , 42 , 43 , 44 , 45 , 46 , 47 , 48 , 49 , 50 , 51 , 52 , 53 , 54 , 55 , 56 , 57 , 58 , 59 , 60 , 61 , 62 , 63 , 64 , 65 , 66 , 67 , 68 , 69 , 70 , 71 , 72 , 73 , 74 , 75 , 76 , 77 , 78 , 79 , 80 , 81 , 82 , 83 , 84 , 85 , 86 , 87 , 88 , 89 , 90]

plt . scatter ( x= measurement , y= temperature , s=25 , c=colors , alpha =0 .6 , edgecolor =’black ’, linewidth =1 ,
cmap =’Blues_r ’)

cbar = plt . colorbar ()
cbar . set_label (’Mesurements with Temperature ’) plt . xscale (’log ’)
plt . yscale (’log ’)
plt . title (’Scatter of Temperature ’)
plt . xlabel (’ Measurement ’)
plt . ylabel (’ Temperature ’)

plt . savefig (" data .png") plt . show ()

if __name__ == " __main__ ": print ( main () )

## 2.3 Plots

### Für die Erklärung siehe: https://github.com/ugurtu/CatcProject/blob/main/ Bericht/bericht.pdf (https://github.com/ugurtu/CatcProject/blob/main/Bericht/bericht.pdf)


## Abbildung 4. Temperaturausgaben über eine bestimme Zeit


## Abbildung 5. Einzelne Messpunkte des DHT22

## 3 Simples Modell

## Arduino:

# i n c l u d e "DHT. h "

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

6 | # d e f i n e pi nG r e e n 5 / / LEDPin5
8 | DHT d ht ( DHTPIN , DHTTYPE ) ;
10 | v oi d s e t u p ( ) {
/ / p ut y o u r s e t u p c o de h e r e , t o r u n o nce : 12 S e r i a l . b e gi n ( 9 6 0 0 ) ;
/ / S e r i a l . p r i n t l n ( "DHT22 Te st p r o g ramm " ) ; 14 pinMode ( pinRed , OUTPUT ) ;
pinMode ( pi nG ree n , OUTPUT ) ;

16
d ht . b e gi n ( ) ;

18
}

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


## Abbildung 6. DHT und LEDs verbunden an Breadboard mit Arduino

# @author Ugur Turhal

# This python file reads the serial port of the Arduino and # reads the state of the LEDs out and Shows the Temperature

import numpy as np
import pandas as pd
import matplotlib . pyplot as plt import serial
import time
import csv
from drawnow import *

plt . style . use (’seaborn ’)
ser = serial . Serial (’/dev/ ttyACM0 ’) ser . flushInput ()

ledRedPin = []
ledGreen = []
temperature = []

def makeFig ():
plt . close ("all")
plt . title (’HIGH and LOW of \n selected pins ’) plt . ylim (0 , 1 .5 , 0 . 4 )

plt . plot ( ledRedPin , label =’ digitalRead_Red ’, color =’red ’) plt . legend ( bbox_to_anchor =( 1 .0 , 0 . 5 ) , loc=’upper left ’)

plt2 = plt . twinx ()
plt . ylim (0 , 30 , 6 )
plt2 . plot ( temperature , label =’C’)
plt2 . legend ( bbox_to_anchor =( 1 .0 , 1 . 01 ) , loc=’upper left ’)

plt3 = plt . twinx () ;
plt . ylim (0 , 1 . 5 )
plt3 . plot ( ledGreen , label =’ digitalRead_Green ’, color =’green ’) plt3 . legend ( bbox_to_anchor =( 1 .0 , 0 ) , loc=’upper left ’)

plt . tight_layout ()
plt . savefig (" digitalRead .png")

def main ():
while True :
ser_bytes = ser . readline () while ser . inWaiting () == 0:
pass
try:
r = float ( ser_bytes [0:1]. decode ("utf -8") ) ;
g = float ( ser_bytes [1:len( ser_bytes ) - 7]. decode ("utf -8") ) ;
temp = float ( ser_bytes [3:len( ser_bytes )]. decode ("utf -8 ") ) ;
ledRedPin . append ( r )
temperature . append ( temp )
ledGreen . append ( g )
drawnow ( makeFig )
except :
continue
print (" ERROR ")
with open (" states .csv", "a") as f: writer = csv . writer (f , delimiter =",") writer . writerow ([r , g , temp ])

if __name__ == ’__main__ ’: print ( main () )

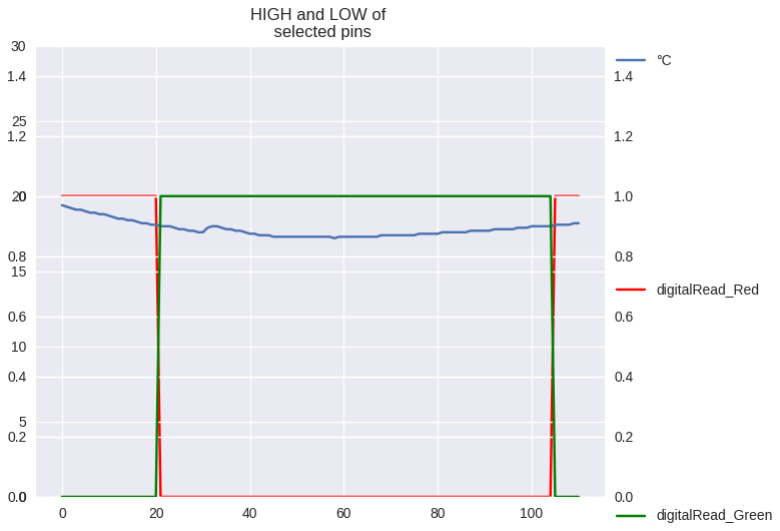
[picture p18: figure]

## Abbildung 7. HIGH und LOW bei bestimmten Temperaturen beim Auslesen des Serial Ports

### Für die Erklärung der Abbildung 7 siehe: https://github.com/ugurtu/CatcProject/

blob/main/Bericht/bericht.pdf (https://github.com/ugurtu/CatcProject/blob/main/Bericht/bericht.pdf)

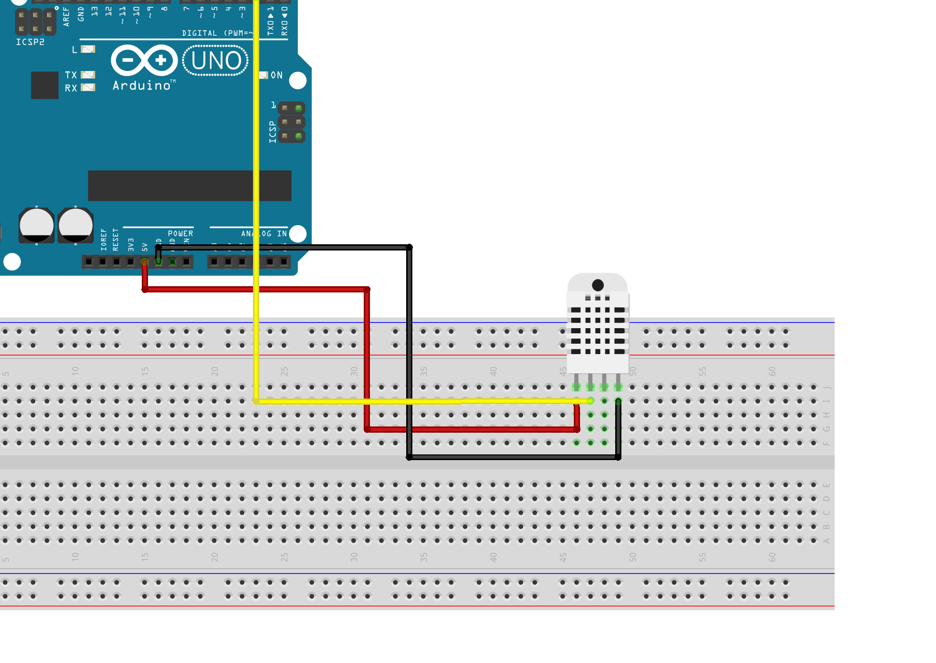
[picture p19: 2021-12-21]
Aufbau DHT, Programme und Daten/pics/pics/wiringdht.png

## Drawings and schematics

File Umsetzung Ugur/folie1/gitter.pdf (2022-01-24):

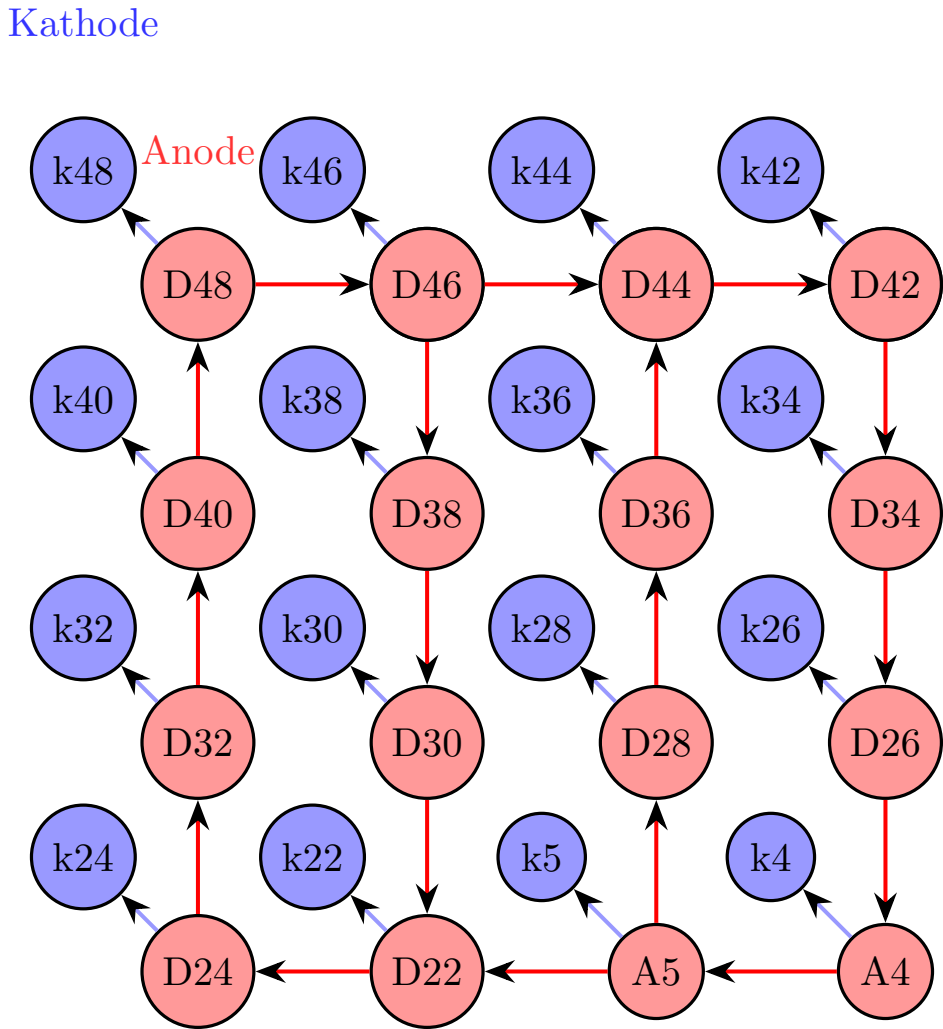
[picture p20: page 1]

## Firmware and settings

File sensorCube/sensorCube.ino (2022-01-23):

 #include "DHT.h"
  
  #define DHTPIN 50 //Pin Nummer wo der Sensor angeschlossen ist
  #define DHTTYPE DHT22 //Definition was fuer ein Sensor ausgelesen wird.
  
  
  //initializing and declaring led rows
    int column[16]={48,46,44,42,40,38,36,34,32,30,28,26,24,22,A4,A5};
    
  //initializing and declaring led layers
    int layer[4]={A3,A2,A1,A0};
  // Setup
  
    float h = 0;
    float t = 0;
  
  long randNumber;
    int time = 250;
  
   DHT dht(DHTPIN, DHTTYPE);
   
  void setup()
  {
    //setting rows to ouput
    for(int i = 0; i<16; i++)
    {
      pinMode(column[i], OUTPUT);
    }
    //setting layers to output
    for(int i = 0; i<4; i++)
    {
      pinMode(layer[i], OUTPUT);
    }
    //seeding random for random pattern
    randomSeed(analogRead(10));
    Serial.begin(9600);
    dht.begin();
  }
  
  // The Loop
  void loop(){
    
     h = dht.readHumidity();
     t = dht.readTemperature();
     printTemp();

     if(t < 15.00){
      coldSleepTemp();
       printTemp();     
     }

    if (t >= 18.00 ){
      hotSleepTemp();
      printTemp();
     }

    else{
      if(h <= 30.00){
        downUpRain();
        printTemp();
      }
      if(h >= 60.00){
        topDownRain();
        printTemp();
      }
      else{
        goodForSleeping();
        printTemp();
      }
     }
  }

  void coldSleepTemp()
    {
      int x = 75;
      for(int i = 0; i<4; i++)
      {
        digitalWrite(layer[i], 0);
      }
      for(int y = 0; y<5; y++)
      {
        for(int count = 0; count<1; count++)
        { 
          for(int i = 4; i>0; i--)
          {
            digitalWrite(layer[i], 1);
            delay(x);
            digitalWrite(layer[i], 0);
          }
          for(int i = 4; i !=0; i--)
          {
            digitalWrite(layer[i-1], 1);
            delay(x);
            digitalWrite(layer[i-1], 0);
          }
        }
        for(int i = 0; i<4; i++)
        {
          digitalWrite(layer[i], 1);
          delay(x);
        }
        for(int i = 4; i!=0; i--)
        {
          digitalWrite(layer[i-1], 0);
          delay(x);
        }
          printTemp(); 
      }
    }
  
    void hotSleepTemp() {
    turnEverythingOff();
    int x = 90;
    for(int y = 4; y>0; y--) {
      for(int i = 0; i<6; i++) {
        //turn on layer
        digitalWrite(layer[y-1], 1);
        //a1
        turnColumnsOff();
        digitalWrite(column[0], 0);
        digitalWrite(column[5], 0);
        digitalWrite(column[10], 0);
        digitalWrite(column[15], 0);
        delay(x);
        //b1
        turnColumnsOff();
        digitalWrite(column[4], 0);
        digitalWrite(column[5], 0);
        digitalWrite(column[10], 0);
        digitalWrite(column[11], 0);
        delay(x);
        //c1
        turnColumnsOff();
        digitalWrite(column[6], 0);
        digitalWrite(column[7], 0);
        digitalWrite(column[8], 0);
        digitalWrite(column[9], 0);
        delay(x);
        //d1
        turnColumnsOff();
        digitalWrite(column[3], 0);
        digitalWrite(column[6], 0);
        digitalWrite(column[9], 0);
        digitalWrite(column[12], 0);
        delay(x);
        //d2
        turnColumnsOff();
        digitalWrite(column[2], 0);
        digitalWrite(column[6], 0);
        digitalWrite(column[9], 0);
        digitalWrite(column[13], 0);
        delay(x);
        //d3
        turnColumnsOff();
        digitalWrite(column[1], 0);
        digitalWrite(column[5], 0);
        digitalWrite(column[10], 0);
        digitalWrite(column[14], 0);
        delay(x);
      }
        printTemp(); 
     }
      //d4
      turnColumnsOff();
      digitalWrite(column[0], 0);
      digitalWrite(column[5], 0);
      digitalWrite(column[10], 0);
      digitalWrite(column[15], 0);
      delay(x);
      printTemp(); 
    }

    void topDownRain() {
      turnEverythingOff();
      int x = 100;
      for(int i = 0; i!=60; i+=2) {
        int randomColumn = random(0,16);
        digitalWrite(column[randomColumn], 0);
        digitalWrite(layer[3], 1);
        delay(x+50);
        digitalWrite(layer[3], 0);
        digitalWrite(layer[2], 1);
        delay(x+115);
        digitalWrite(layer[2], 0);
        digitalWrite(layer[1], 1);
        delay(x+250);
        digitalWrite(layer[1], 0);
        digitalWrite(layer[0], 1);
        delay(x+50);
        digitalWrite(layer[0], 0);
        digitalWrite(column[randomColumn], 1);
         h = dht.readHumidity();
         t = dht.readTemperature();
        printTemp();
      }
    }
  
  void downUpRain()
  {
    turnEverythingOff();
    int x = 100;
    for(int i = 0; i!=60; i+=2)
    {
      int randomColumn = random(0,16);
      digitalWrite(column[randomColumn], 0);
      digitalWrite(layer[0], 1);
      delay(x+50);
      digitalWrite(layer[0], 0);
      digitalWrite(layer[1], 1);
      delay(x+115);
      digitalWrite(layer[1], 0);
      digitalWrite(layer[2], 1);
      delay(x+250);
      digitalWrite(layer[2], 0);
      digitalWrite(layer[3], 1);
      delay(x+50);
      digitalWrite(layer[3], 0);
      digitalWrite(column[randomColumn], 1);
     h = dht.readHumidity();
     t = dht.readTemperature();
     printTemp();
    }
  }

    void goodForSleeping()
  {
    turnEverythingOff();
    int x = 1000;
    for(int i = 0; i<16; i++)
    {
      digitalWrite(column[i], 0);
    }
    //turning on layers
    for(int i = 0; i<2; i++)
    {
      digitalWrite(layer[i], 1);
    }
    delay(x);
  }
  
  void turnColumnsOff()
  {
    for(int i = 0; i<16; i++)
    {
      digitalWrite(column[i], 1);
    }
      printTemp(); 
  }
  
  void printTemp(){
     h = dht.readHumidity();
     t = dht.readTemperature();
     Serial.print("Humidity in % ");
     Serial.print(h);
     Serial.print(" Temperature in °C: ");
     Serial.println(t); 
    }
    
  void turnEverythingOn() {
    for(int i = 0; i<16; i++)
    {
      digitalWrite(column[i], 0);
    }
    //turning on layers
    for(int i = 0; i<4; i++)
    {
      digitalWrite(layer[i], 1);
    }
  }
  
  void turnEverythingOff() {
     for(int i = 0; i<16; i++)
     {
       digitalWrite(column[i], 1);
     }
     for(int i = 0; i<4; i++)
     {
       digitalWrite(layer[i], 0);
     }
   }
